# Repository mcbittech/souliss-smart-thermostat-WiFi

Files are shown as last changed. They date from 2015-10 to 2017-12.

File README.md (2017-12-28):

# souliss-smart-thermostat-WiFi


Wi-Fi Smart Thermostat based on Souliss IoT Framework

Youtube video:
https://youtu.be/Pk9kK5DvYXE

[Wiki-How to Compile & Upload](https://github.com/mcbittech/souliss-smart-thermostat-WiFi/wiki/SST---WiFi-Souliss-Smart-Thermostat-Wiki)

# Example of SST with 3D printed support & cover:
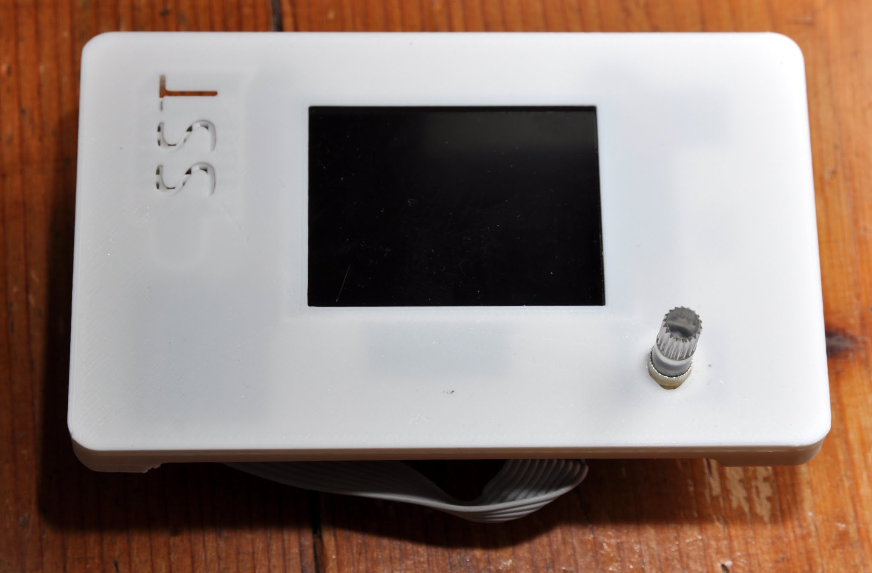
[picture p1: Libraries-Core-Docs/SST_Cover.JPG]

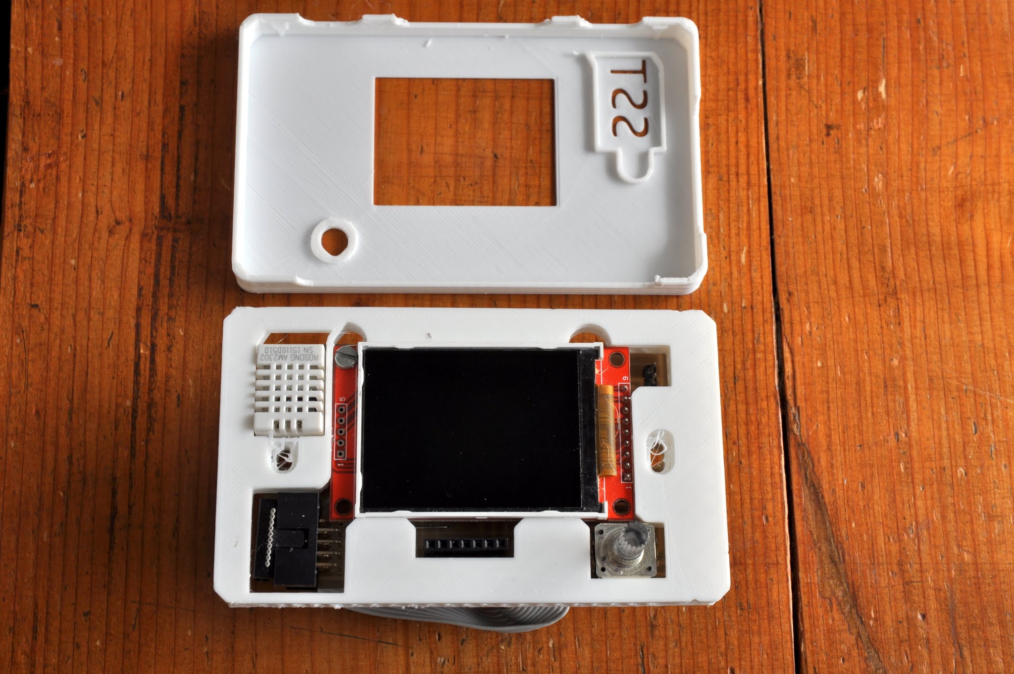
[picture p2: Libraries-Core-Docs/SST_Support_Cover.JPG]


# Example of layout 2:
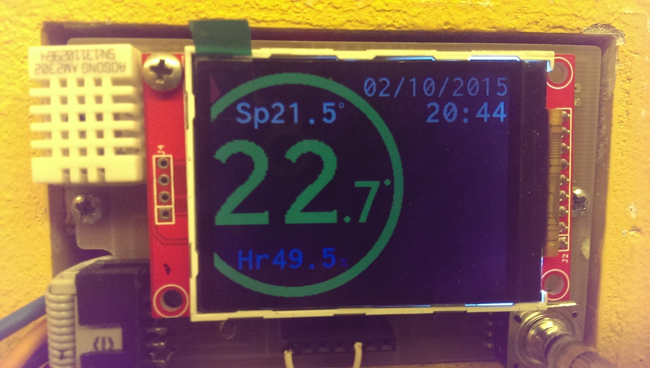
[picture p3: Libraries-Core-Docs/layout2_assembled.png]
layout2


# Example of layout 1:
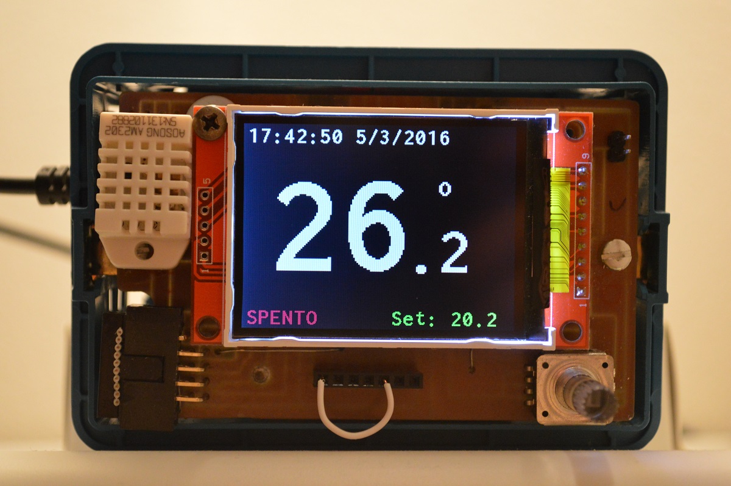
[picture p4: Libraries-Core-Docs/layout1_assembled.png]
layout2 layout1


# Example of chrono:
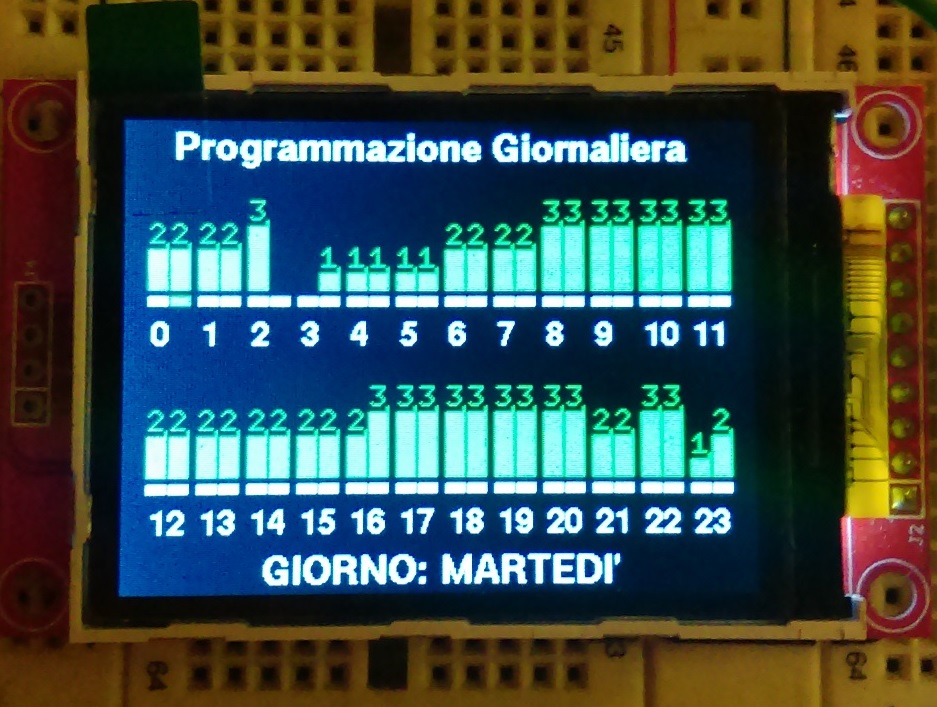
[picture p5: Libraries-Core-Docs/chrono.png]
chrono


# Bill of Material:
-Olimex ESP8266-EVB  
-ILI9341 with SPI connection, via UEXT connector  
-Rotary Encoder with pushbutton & status LED  
-DHT22 Temperature & Humidity Sensor  

# How to connect your system:
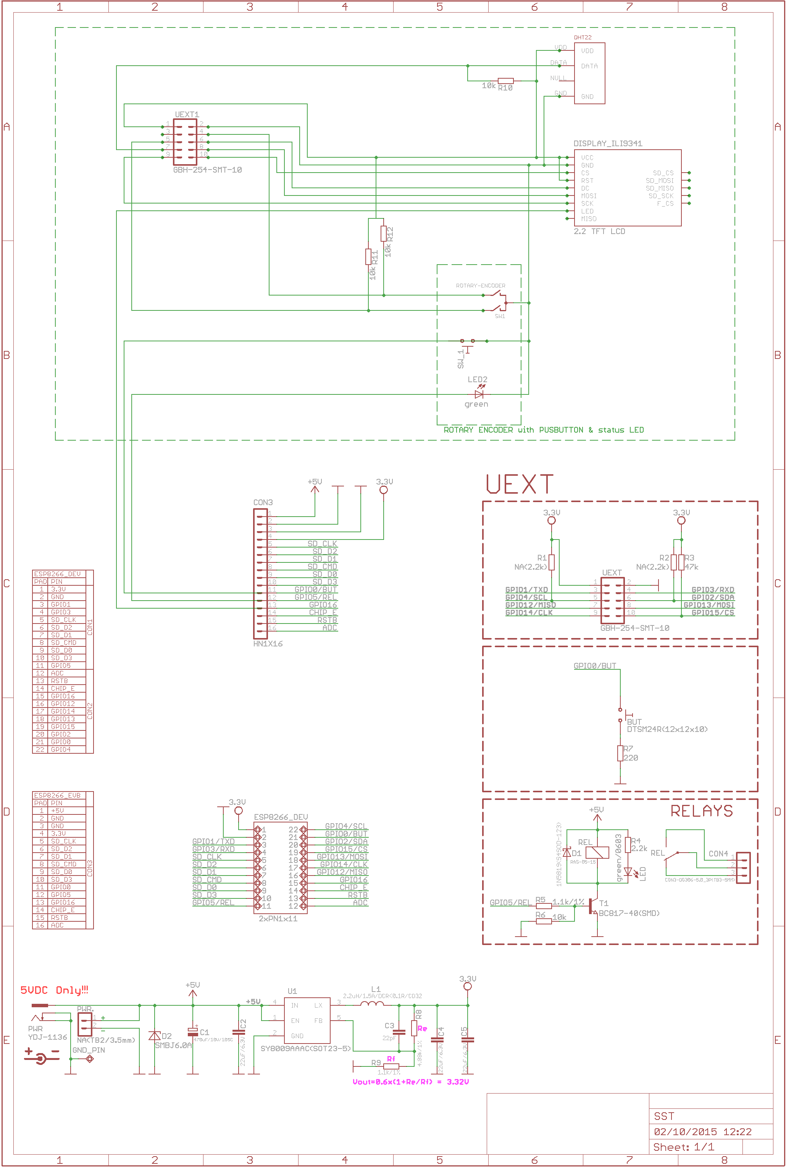
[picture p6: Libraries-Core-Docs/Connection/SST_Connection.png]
scheme


# Power up your system:
All the system require maximum about 200mA @5vdc, with relay ON and maximum brightness of the screen.
Minimum power required about 65mA, with relay OFF and minimum brightness.

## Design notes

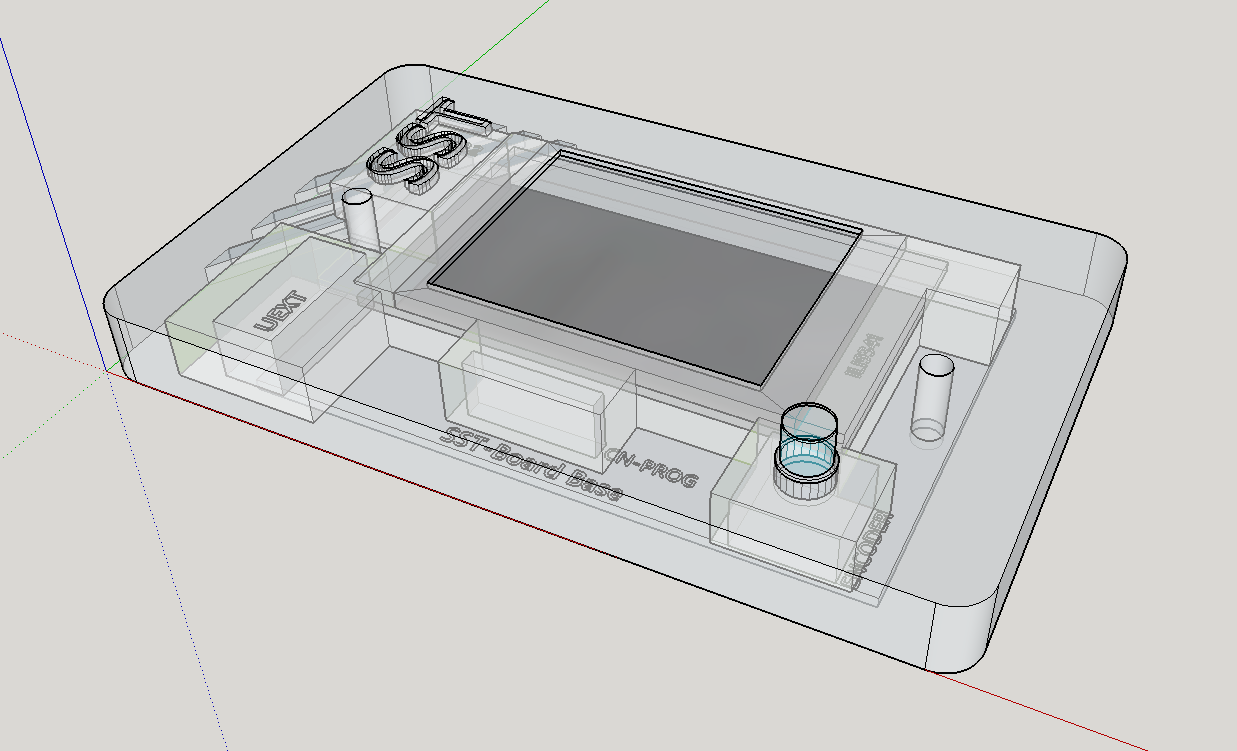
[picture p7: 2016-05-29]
Libraries-Core-Docs/MOSTRINA_3D/Prototipo.png

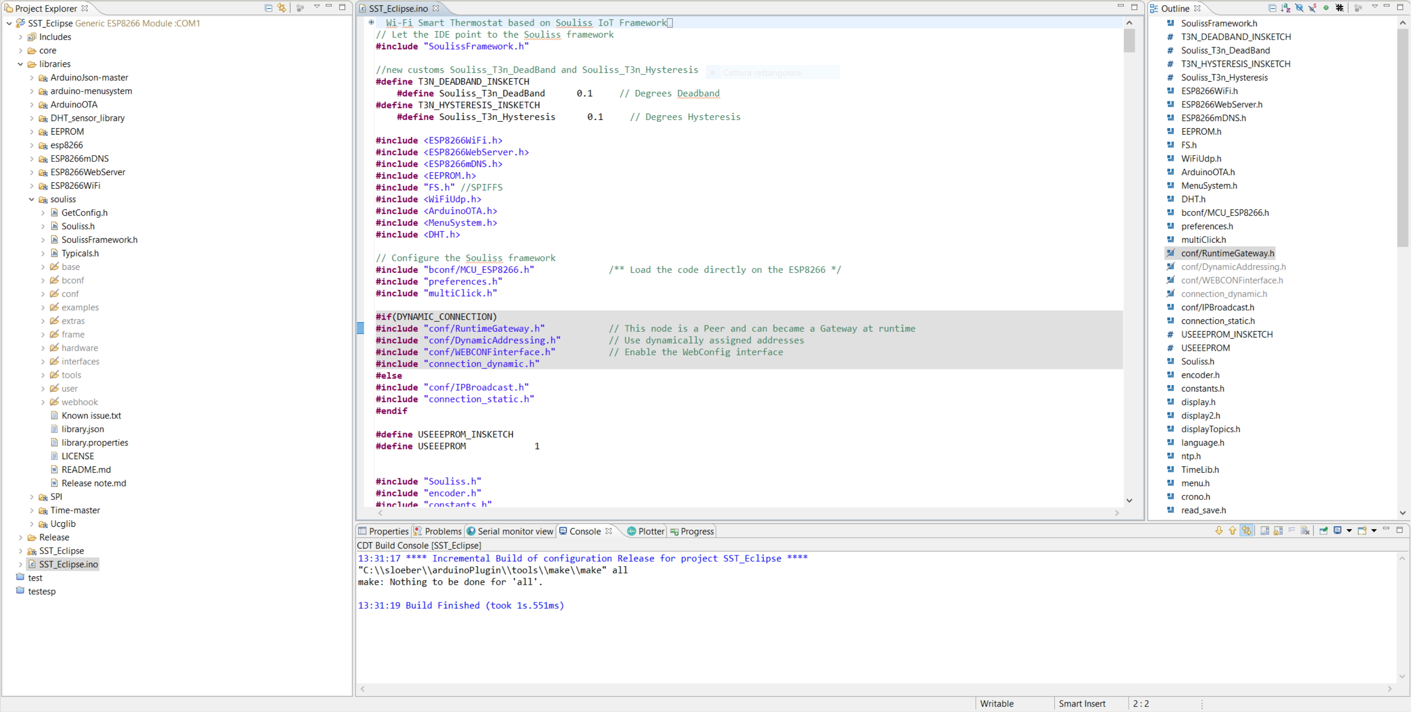
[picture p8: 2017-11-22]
Libraries-Core-Docs/SST_Eclipse.PNG

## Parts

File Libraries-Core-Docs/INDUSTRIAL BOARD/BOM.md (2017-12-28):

## BOM:
| Ref | Qty  | Value |
|:---|:---:|:---|
|C1 |1 |100n|
|C6,C5 |2 |470n 10v|
|D1 |1 |LED Rosso|
|D2 |1 |1N5819|
|D4 |1 |LED Verde|
|DHT1 |1 |DHT22|
|DISPLAY1 |1 |ILI9341|
|K2 |1 |CONN_3|
|P1,P2,P4 |3 |CONN_2|
|P3,P6 |2 |CONN_6|
|P5 |1 |CONN_5|
|POT1 |1 |EC12PL|
|Q1 |1 |BC818-40|
|R10,R5,*R9,R3,R14,R13,R16,R6  |8 |10k |
|R4,R1 |2 |1k |
|R7,R8,R2,R15  |4 |2.2k |
|RL1 |1 |RELAY_1RT |
|SW1 |1 |SW_PUSH |
|T1 |1 |VTX-214-005-105 |
|U1 |1 |ESP-12E |
|U2 |1 |LD1085-33 |

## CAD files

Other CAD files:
Libraries-Core-Docs/MOSTRINA_3D/Taglio.dwg
Libraries-Core-Docs/MOSTRINA_3D/Studio.skp

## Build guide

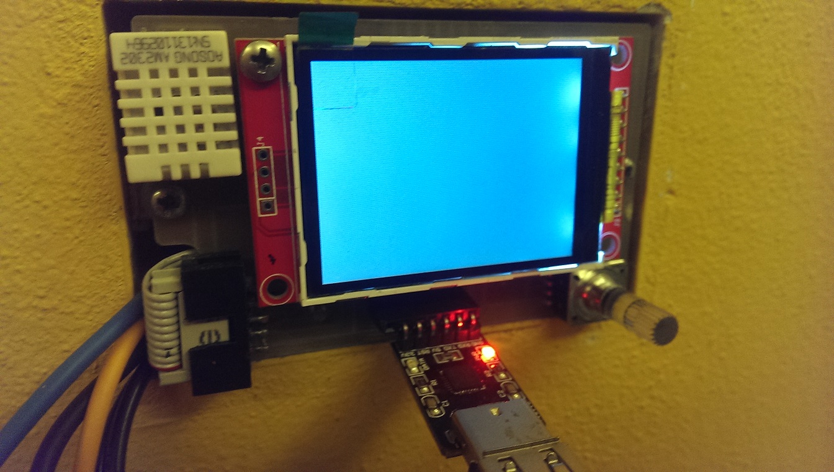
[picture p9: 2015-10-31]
Libraries-Core-Docs/howto_program.png

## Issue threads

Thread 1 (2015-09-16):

AnalogWrite function break display library

mcbittech, 2015-09-16:
Using AnalogWrite function on GPIO16(display LED backlight) will cause a break of display.

mcbittech, 2015-09-27:
With new library, i can't reproduce the problem.
Now working fine.

Closed 2015-09-27.

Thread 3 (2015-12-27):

Link non valido allo schema

dariocdj, 2015-12-27:
Ciao,
https://github.com/mcbittech/souliss-smart-thermostat-WiFi/blob/master/SST_Connection.png?raw=true
non si vede più....
Mi sta arrivando il materiale....
grazie

Dario

mcbittech, 2015-12-27:
Closed #3 with commit 544596e

mcbittech, 2015-12-27:
Closed #3
<https://github.com/mcbittech/souliss-smart-thermostat-WiFi/issues/3> with
commit 544596e
<https://github.com/mcbittech/souliss-smart-thermostat-WiFi/commit/544596eebb0ce489a9f942bdad8f74ab6ae5b138>

2015-12-27 21:49 GMT+01:00 Dario <notifications@github.com>:

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

--
P ********* Consideriamo l'ambiente prima di stampare questa e-mail ***
Think about environment before printing *********
Il contenuto di questo messaggio e-mail è privato e riservato al solo
destinatario. L'utilizzo non autorizzato può costituire reato. Se ricevuto
erroneamente siete pregati di cancellarlo e comunicarci via e-mail l'errata
ricezione.

dariocdj, 2015-12-27:
grazie

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

--

-------------------------------------------------------------------
                    Dario ??Cdj??

      On Email: cdj@deskservice.com
      On Web  : http://www.cdj.deskservice.com
      On Irc  : Undernet.org #altraitalia
      On ICQ  : Uin # 3986985
      On MSN  : dariocdj@hotmail.it
      On Skype: dariocdj

                Send me a fast reply !!!
------------------------------------------------------------------

Closed 2015-12-27.

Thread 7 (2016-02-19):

Arduino OTA

fazioa, 2016-02-19:

fazioa, 2016-02-24:
Implementata la modalità webupdater.
La relativa pagina web funziona e l'upload del nuovo sketch inizia correttamente.
L'upload non arriva al 50% e la pagina va in timeout.
Attendiamo upgrade del core e dell'IDE.

Closed 2016-02-24.

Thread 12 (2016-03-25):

OH continuous refresh on "off" state

dariocdj, 2016-03-25:
Today i 've found my sst in "off" position correctly but in oh logs:

14:35:35.935 [DEBUG] [.b.s.i.n.udp.UDPSoulissDecoder:80   ] - updateTIMESTAMP:  TIMESTAMP_Nodo12 ( 153) = 2016-03-21T14:35:35.935CET
14:35:35.938 [DEBUG] [.s.i.n.t.SoulissGenericTypical:100  ] - Update State. Name: power, Typ: 0x11, Node: 12, Slot: 0. New State: 0.0
14:35:35.951 [DEBUG] [.s.i.n.t.SoulissGenericTypical:100  ] - Update State. Name: heating, Typ: 0x13, Node: 12, Slot: 0. New State: 0.0
14:35:35.955 [DEBUG] [.s.i.n.t.SoulissGenericTypical:100  ] - Update State. Name: cooling, Typ: 0x13, Node: 12, Slot: 0. New State: 0.0
14:35:35.957 [DEBUG] [.s.i.n.t.SoulissGenericTypical:100  ] - Update State. Name: fan_low, Typ: 0x11, Node: 12, Slot: 0. New State: 0.0
14:35:35.961 [DEBUG] [.s.i.n.t.SoulissGenericTypical:100  ] - Update State. Name: fan_med, Typ: 0x11, Node: 12, Slot: 0. New State: 0.0
14:35:35.970 [DEBUG] [.s.i.n.t.SoulissGenericTypical:100  ] - Update State. Name: null, Typ: 0x11, Node: 12, Slot: 0. New State: 0.0
14:35:35.974 [DEBUG] [.s.i.n.t.SoulissGenericTypical:100  ] - Update State. Name: fan_auto_mode, Typ: 0x11, Node: 12, Slot: 0. New State: 0.0
14:35:35.977 [DEBUG] [.s.i.n.t.SoulissGenericTypical:100  ] - Update State. Name: heating_cooling, Typ: 0x11, Node: 12, Slot: 0. New State: 1.0
14:35:35.980 [DEBUG] [.b.s.i.n.udp.UDPSoulissDecoder:300  ] - decodeStateRequest: power (49). Thermostat= 128, Temp.Measured= 20.796875, Temp.SetPoint= 20.796875
14:35:35.991 [DEBUG] [.o.b.s.i.n.udp.UDPServerThread:61   ] - Packet received

This happen continuously...

fazioa, 2016-06-02:
Dario, the issue still exists?

dariocdj, 2016-06-02:
No close it, tnx

Closed 2016-06-02.

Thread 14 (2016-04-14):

Various bugs using ide 1.6.8, core 2.1 and Souliss_Branch_Core2

dariocdj, 2016-04-14:
Tried to modify main page with new OTA (working but erasing eeprom) but new core and souliss_branch_core2 introduce several bugs :
1) during crono programming moving encoder in setpoint area cause reset.
2) t31 work reversed. It start in heat mode but with no functional relay
3) sometimes system send lots of data to gateway (floods) with t31 reversed.
4) eeprom doesn't work well

Closed 2016-06-02.

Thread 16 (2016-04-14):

Moving Encoder in Topics page cause setpoint printing

dariocdj, 2016-04-14:
In layout2 When you move encoder while you are in topics page new setpoint is printed. And this is not good.

fazioa, 2016-06-02:
Only Circular layout is affected

dariocdj, 2016-06-02:
I know but no idea how to fix it....

mcbittech, 2017-12-11:
#54 solve this

Closed 2017-12-11.

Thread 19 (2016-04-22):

child lock

fazioa, 2016-04-22:
Proposta: doppio click per inserire il blocco bambini, nuovamente doppio click per disinserito.
Il blocco bambini dovrebbe impedire di cambiare il Setpoint

dariocdj, 2016-04-22:
+1

fazioa, 2016-08-15:
Done

https://github.com/mcbittech/souliss-smart-thermostat-WiFi/commit/65a79166d2863b79006466aa379e8db51ddd56f0

Closed 2016-08-15.

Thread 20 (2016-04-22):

Menu responsive

fazioa, 2016-04-22:
Rendere più reattiva la navigazione del menu

fazioa, 2016-06-02:
E' il refresh a video che rallenta la selezione. Occorre migliorere la funzione del file menu.cpp
void printMenu(Ucglib_ILI9341_18x240x320_HWSPI ucg)

Closed 2016-06-09.

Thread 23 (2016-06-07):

Ora legale

dariocdj, 2016-06-07:
Prevedere flag ora legale. Con timezone 1 segna un ora prima....

dariocdj, 2016-06-13:
Added DayLightSavingTime (ora legale) in getNtpTime function and in submenu "clock" but not considered when print time. Pheraps setSyncProvider(getNtpTime); doesn't work ?

fazioa, 2016-08-18:
Fixed
https://github.com/mcbittech/souliss-smart-thermostat-WiFi/commit/36d52be59ecdbdf8b41ebeaef9e481f595d6ddfe

Closed 2016-08-18.

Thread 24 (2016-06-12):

Layout Circular - Shift Digit

fazioa, 2016-06-12:
Some digit shift on the right when Hr is Nan

dariocdj, 2016-06-13:
In logs it shift after :
Refresh Temperature to: 2147483647.2147483647
Refresh Humidity to: nan
exactely...

fazioa, 2016-08-15:
With DTH22 NaN fix , it could be fixed

Closed 2016-08-15.

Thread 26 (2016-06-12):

Layout Circular freeze when print circles

fazioa, 2016-06-12:

mcbittech, 2016-06-12:
@fazioa can you explain better this issue?
Core ide etc...
With the released code i've never see this issue.

Il domenica 12 giugno 2016, fazioa <notifications@github.com> ha scritto:

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

--
P ********* Consideriamo l'ambiente prima di stampare questa e-mail ***
Think about environment before printing *********
Il contenuto di questo messaggio e-mail è privato e riservato al solo
destinatario. L'utilizzo non autorizzato può costituire reato. Se ricevuto
erroneamente siete pregati di cancellarlo e comunicarci via e-mail l'errata
ricezione.

mcbittech, 2016-09-21:
closed

Closed 2016-09-21.

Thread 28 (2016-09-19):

Child Lock not visible on layout 2

dariocdj, 2016-09-19:
Some printing of "child lock" is necessary on layout 2

dariocdj, 2016-09-23:
fixed but need refresh after changing state (locked or unclocked).
setUIChanged() unsuccessful !

dariocdj, 2016-09-26:
Need refresh

dariocdj, 2016-09-26:
Ok fixed reinitializing HomeScreen

Closed 2016-09-26.

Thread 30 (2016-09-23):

Layout2 Crono status in topics and menu pages

dariocdj, 2016-09-23:
When crono refresh, display status also if in topics or menu pages...

dariocdj, 2016-09-26:
Fixed with checkCronoStatus and printing status from main file only if crono is on, homepage is selected, layout is 2

Closed 2016-09-26.

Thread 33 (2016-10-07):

temperature decimal not diplay .4 or .9

mcbittech, 2016-10-07:
in temperature visualization you never see xx.4 or xx.9
bug of function dopovirgola()

mcbittech, 2016-10-07:
waiting for test

mcbittech, 2016-10-26:
Seems to be ok

Closed 2016-10-26.

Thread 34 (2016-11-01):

Files compiled with errors

igbor, 2016-11-01:
Files compiled with errors. Established Arduino AVR v1.6.11 ESP 8266 v2.3.0 Souliss v.7.2.1

C:\Users\igbor\Documents\Arduino\e05_ESP8266_SST_webconf\e05_ESP8266_SST_webconf.ino: In function 'void subscribeTopics()':

e05_ESP8266_SST_webconf:114: error: 'subscribedata' was not declared in this scope
   if (subscribedata(TOPIC1, mypayload, &mypayload_len)) {
                                                                                          ^
C:\Users\igbor\Documents\Arduino\e05_ESP8266_SST_webconf\e05_ESP8266_SST_webconf.ino: In function 'void publishHeating_ON_OFF()':

e05_ESP8266_SST_webconf:248: error: 'publishdata' was not declared in this scope
     publishdata(SST_HEAT_ONOFF, &HEAT_ON, 1);
                                                                            ^
e05_ESP8266_SST_webconf:250: error: 'publishdata' was not declared in this scope
     publishdata(SST_HEAT_ONOFF, &HEAT_OFF, 1);
                                                                              ^
exit status 1
'subscribedata' was not declared in this scope

fazioa, 2016-11-01:
In last Souliss release subscribedata as changed in sbscrb and publish
in pblsh

Look at .\souliss\base\PublishSubscribe.h

Tonino Fazio

2016-11-01 7:22 GMT+01:00 igbor <notifications@github.com>:

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

mcbittech, 2016-11-08:
@igbor have you solved?

igbor, 2016-11-09:
Thank you for all compiles fine, the author has made changes. Upgrade to github

Closed 2016-11-09.

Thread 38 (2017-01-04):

ESP-12E Random Soft WDT Resets

brunodymios, 2017-01-04:
Hi there,
I'm really interested in this project and I'm testing it on a NodeMCU ESP-12E development board.
I randomly receive software WDT resets. It can happen right after 10 minutes or a couple of hours, it is not sistematic. It happens both when powered with USB and with an external power supply (7805 connected to the Vin pin of the board).

Here you are the stacktrace I'm receiveing in the serial monitor window:

```
Refresh Circle White
Refresh Circle White OK
Refresh Circle Black
Refresh Circle Black OK
Refresh HOME Screen

Soft WDT reset

ctx: cont
sp: 3fff1640 end: 3fff1bd0 offset: 01b0

>>>stack>>>
3fff17f0:  3fff0a40 3fff1810 00000029 40215609
3fff1800:  00000000 3fff1ad8 3fff1ab8 4021a54b
3fff1810:  00000000 0000000e 00000005 00000030
3fff1820:  00000001 3fff1ad8 3fff1ab8 4021a864
3fff1830:  40215482 63045964 00000020 401076bc
3fff1840:  3fffc278 3fff1ad8 3fff1ab8 4021a8f3
3fff1850:  402154b1 00000030 3fff1ab8 4021ba14
3fff1860:  4021549b 3fff1ad8 3fff1ab8 4021bced
3fff1870:  00000025 0000005a 0000fff8 fffffff8
3fff1880:  000000b4 000000b4 0000004a 00000015
3fff1890:  4021549b 00000030 00000008 0000003b
3fff18a0:  00000025 00000039 3fff1ab8 40247f5d
3fff18b0:  fc0000ff 402154e0 402154e0 4021b27b
3fff18c0:  000000a4 00000055 27f40000 4021ad68
3fff18d0:  00000000 0000003b 00000000 fffffffc
3fff18e0:  0000003b 00000000 00000025 401076bc
3fff18f0:  4021a8a4 0000000f 3fffc230 0000003f
3fff1900:  00000000 3fff1ab8 3fff1b34 4021ae4d
3fff1910:  00000025 0000003e ffffffcf 00000000
3fff1920:  4021b97c 00000000 000000ff 3fff1ab8
3fff1930:  fffffffc 00000000 3fff1ab8 4021af03
3fff1940:  3fff1ab8 00000050 00000000 4021b000
3fff1950:  00000031 00000001 3fff1ab8 40219d28
3fff1960:  00009b98 00000000 3fff1ab8 3fff19f0
3fff1970:  3fff1ab0 00000000 3fff1ab0 40215685
3fff1980:  000000c5 00000002 3fff19ee 4021892c
3fff1990:  4000df64 00000030 00000011 3fff1ab0
3fff19a0:  00000031 0000000a 3fff1ab0 402160f1
3fff19b0:  3fff19ee 3fff1a30 3fff1ab8 4021a8f3
3fff19c0:  000000a3 3fff1a20 3fff19ed 402162ad
3fff19d0:  3fff00f0 3fff1a30 3fff1ab8 4021bd51
3fff19e0:  00000000 3fff1a20 3fff1ab8 3831b9b1
3fff19f0:  3fff1c00 3fff1aba 3fff1ab8 00000009
3fff1a00:  00000009 3fff1ab8 3fff1ab8 00000009
3fff1a10:  3fff1c18 3fff1ab8 3fff1ab8 00000009
3fff1a20:  3fff1c18 00000012 3fff1ab0 4021630b
3fff1a30:  00000000 014000f0 3fff1ab8 40247f29
3fff1a40:  3fff1c18 3fff1ab8 3fff1ab0 40216324
3fff1a50:  41973333 41973333 3fff1ab0 4020a751
3fff1a60:  00000012 41a00000 4288cccd 402161ec
3fff1a70:  00000000 3fff1c18 3fff1c18 40216238
3fff1a80:  3fff0226 3fff1c18 3fff1ab8 3fff0ba4
3fff1a90:  00000000 3fff0224 3fff00f0 4020ebc3
3fff1aa0:  40000f83 00000030 00000020 401076bc
3fff1ab0:  3ffe89b0 00000000 00a00001 00000078
3fff1ac0:  4021bba8 4021a880 4021a8a4 014000f0
3fff1ad0:  4021b97c 402154e0 0000003b 00000000
3fff1ae0:  00010042 00010008 00000000 ff660000
3fff1af0:  00000000 00000000 00000000 00000000
3fff1b00:  00000000 00000000 00000000 00000000
3fff1b10:  00000000 00000000 00000000 00000000
3fff1b20:  00000000 00000000 014000f0 4024e9e4
3fff1b30:  4021a9dc 4024ef11 001ffffc 3e253a1f
3fff1b40:  00000001 0506025f 05010606 003e2507
3fff1b50:  30f42ef3 098400f3 000014de 00000000
3fff1b60:  02fff42e ffffff0f ffffffff 07ffffff
3fff1b70:  0000010d 4021a8a4 4021a880 0050fffc
3fff1b80:  feefef00 3fff2b34 3fff267c 00000000
3fff1b90:  00000000 00000000 feefeffe feefeffe
3fff1ba0:  00000000 00000000 00000001 3fff0ba4
3fff1bb0:  3fffdad0 00000000 3fff0b9c 4021588c
3fff1bc0:  feefeffe feefeffe 3fff0bb0 40100718
<<<stack<<<

 ets Jan  8 2013,rst cause:2, boot mode:(3,6)

load 0x4010f000, len 1384, room 16
tail 8
chksum 0x2d
csum 0x2d
v3de0c112
~ld
ÿ

```
Addresses shown before the stack trace are not fixed, they change between subsequent crashes. Here's another crash log, right after the first one:

```
Refresh Circle Green
Refresh Circle Green OK

Soft WDT reset

ctx: cont
sp: 3fff16c0 end: 3fff1bd0 offset: 01b0

>>>stack>>>
```

At the beginning of the code, in the setup() I've added some additional debug info:
```
Heap: 37424
Boot Vers: 31
CPU: 80
SDK: 1.5.3(aec24ac9)
Chip ID: 422598
Flash ID: 1458400
Flash Size: 4194304
Vcc: 65535
```

Boot mode (3,6) seems to be correct: booting from SPI flash memory, while the reset cause (2) means that there is something with the RST pin. I checked the connections and they are OK and I added a 10k pull-up resistor on the GPIO 0 pin, with no luck.

Anyone facing this problem? Any hint to solve it?

Thank You

mcbittech, 2017-01-04:
Hello @brunodymios ,
what kind of release are you working on? your general hardware and schematics?
Are you uploading your code following wiki?
https://github.com/mcbittech/souliss-smart-thermostat-WiFi/wiki/SST---WiFi-Souliss-Smart-Thermostat-Wiki

Flavio

brunodymios, 2017-01-04:
Hi @mcbittech, thanks for your answer.
Yes, I followed the wiki you linked me to setup the firmware (branch "friariello" for souliss and this repo for the thermostat-specific code). I'm using Arduino IDE **1.6.5** with ESP8266 board version **2.3.0** installed.

I'm using a **NodeMCU** board found on banggood. [Here's the link](http://www.banggood.com/it/NodeMcu-Lua-WIFI-Internet-Things-Development-Board-Based-ESP8266-CP2102-Wireless-Module-p-1097112.html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).
The LCD is similar to your one [Link](http://www.banggood.com/it/2_2-Inch-Serial-TFT-SPI-LCD-Screen-Module-HD-240-x-320-5110-Compatible-p-912854.html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).
DHT22 is used for Temp/Humidity sensor.

I didn't connect any relay for the moment in order to minimize the complexity of the schematic for testing. I'm using a simple resistor + led to simulate it. All the schematic is built on a breadboard to prototype.

The device is generally working well: temperature and humidity correctly displayed, user menu, set point, etc. Reboots seems to be really random, always with same reason (2 - rst pin and boot mode 3,6) but stack traces point to different memory locations.

Bruno

mcbittech, 2017-01-04:
@brunodymios
Can you try with last IDE supported 1.6.12 please, with [this ](https://github.com/mcbittech/souliss-smart-thermostat-WiFi/releases/tag/SST_v1.2_prewbs_STABLE)version of SST?
Your rst pin are floating or connected?
We haven't tried with this ESP board, if this tests doesen't work, we must go deeper inside hardware/pinout of your board. In this case please attach a schematics of your board.

Flavio

brunodymios, 2017-01-04:
@mcbittech
I've tried right now. I updated the IDE to the 1.6.12 version and I used the version of SST you indicated me (including libraries). I added a 10k pull-up resistor to the RST and GPIO0 pins.

I received a reboot after a couple of minutes the following stack trace:
```
>>>stack>>>
3fff18c0:  00000000 00000000 3fff1b98 40219b64
3fff18d0:  3fff0a30 3fff18f0 00000008 402145f3
3fff18e0:  00000000 3fff1bb8 3fff1b98 4021a387
3fff18f0:  3f00ff66 40101933 04000000 00000001
3fff1900:  00000001 3fff1bb8 3fff1b98 4021a6a0
3fff1910:  00000000 00000000 3fffc230 4000050c
3fff1920:  4021ace4 3fff1bb8 3fff1b98 4021a72f
3fff1930:  4021ad35 4024e9fc 3fff1b98 4021b850
3fff1940:  00000000 3fff1bb8 3fff1b98 4021bb29
3fff1950:  00000007 00000034 0000002a 0000002a
3fff1960:  00000068 00000068 0000000e 00000015
3fff1970:  00000000 3fff1b98 00000020 00000015
3fff1980:  0000000c 00000007 3fff1b98 40247d45
3fff1990:  4021a665 00000030 3fffc230 4021b0b7
3fff19a0:  40219ed8 00000030 0000001d 4021aba4
3fff19b0:  00000019 00000015 00000001 00000015
3fff19c0:  00000015 00000000 00000007 00000066
3fff19d0:  00000000 00000085 00000000 0000001e
3fff19e0:  00000007 3fff1b98 3fff1c14 4021ac92
3fff19f0:  00000025 0000003e ffffffcf 00000000
3fff1a00:  00000000 00000007 00000055 3fff1b98
3fff1a10:  fffffffc 00000000 3fff1b98 4021ad3f
3fff1a20:  0000006e 00000050 00000000 4021ae3c
3fff1a30:  00000032 00000001 3fff1b98 40219b64
3fff1a40:  00009b10 00000000 3fff1b98 3fff1ad0
3fff1a50:  3fff1b90 00000000 3fff1b90 40214679
3fff1a60:  000000c5 00000002 3fff1ace 402187a4
3fff1a70:  3fff0a30 00000001 3fff1b98 3fff1b90
3fff1a80:  00000032 0000000a 3fff1b90 40215d1d
3fff1a90:  3fff1ace 3fff1b10 3fff1b98 4021a72f
3fff1aa0:  00000000 3fff1b00 3fff1acd 40215ed9
3fff1ab0:  00000009 3fff1b10 3fff1b98 4021bb8d
3fff1ac0:  00000000 3fff1b00 3fff1b98 3132b7ed
3fff1ad0:  3fff0b00 3fff1b9a 3fff1b98 00000004
3fff1ae0:  00000009 3fff1b98 3fff1b98 00000004
3fff1af0:  3fff0bc0 3fff1b98 3fff1b98 00000004
3fff1b00:  3fff0bc0 00000015 3fff1b90 40215f37
3fff1b10:  00000000 014000f0 3fff1b98 40247d11
3fff1b20:  3fff0bc0 3fff1b98 3fff1b90 40215f50
3fff1b30:  41ab3333 41ab3333 3fff1b90 4020a751
3fff1b40:  00000015 41a00000 4271999a 40215e18
3fff1b50:  00000000 3fff0bc0 3fff0bc0 40215e64
3fff1b60:  40217cd8 3fff0bc0 3fff1b98 3fff0c7c
3fff1b70:  00000000 3fff0224 3fff00f0 4020eae7
3fff1b80:  40000f83 00000030 0000000e ffffffff
3fff1b90:  3ffe89b0 00000000 00a00001 00000078
3fff1ba0:  4021b9e4 4021a6bc 4021a6e0 014000f0
3fff1bb0:  4021b7b8 402144d4 002a0087 0000ff66
3fff1bc0:  0001000e 00010000 00000000 ff660000
3fff1bd0:  00000000 00000000 00000000 00000000
3fff1be0:  00000000 00000000 00000000 00000000
3fff1bf0:  00000000 00000000 00000000 00000000
3fff1c00:  00000000 00000000 014000f0 4024e7cc
3fff1c10:  4021a818 4024ed21 001ffffc 3e251519
3fff1c20:  00000004 0506025f 05010606 003e2507
3fff1c30:  30f42ef3 098400f3 000014de 00000000
3fff1c40:  02fff42e ffffff0f ffffffff 07ffffff
3fff1c50:  0000010d 4021a6e0 4021a6bc 0050fffc
3fff1c60:  feefef00 3fff2b3c 3fff2684 00000000
3fff1c70:  00000000 00000000 feefeffe feefeffe
3fff1c80:  00000000 00000000 00000001 3fff0c7c
3fff1c90:  3fffdad0 00000000 3fff0c74 40216e30
3fff1ca0:  feefeffe feefeffe 3fff0c90 40100718
<<<stack<<<
```

Decoding it using the [ESP Exception Decoder](https://github.com/me-no-dev/EspExceptionDecoder) I got this information:
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
mcbittech, 2017-01-04:
@brunodymios
try to add some yield(); from [line](https://github.com/mcbittech/souliss-smart-thermostat-WiFi/blob/master/e05_ESP8266_SST_webconf/e05_ESP8266_SST_webconf.ino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)

something like this:
**yield();**
            display_layout2_print_circle_white(ucg);
**yield();**
            display_layout2_print_circle_black(ucg);
**yield();**
            display_layout2_HomeScreen(ucg, temperature, humidity, setpoint);
**yield();**
            display_layout2_print_datetime(ucg);
**yield();**

Then try to move your display pin to other free pins, pin like 2 and 15 to other position.

Let me now

Flavio

brunodymios, 2017-01-05:
Hi @mcbittech
following your indication I added the yield instructions and the device was up and running from 4pm yesterday to 11am this morning without reboots.

As a final test, I flashed again the version without the yield instructions and I saw again a reboot in about 20 minutes.

What do you think? Can we consider this issue closed?

Thank You
Bruno

mcbittech, 2017-01-05:
@brunodymios i don't think this is an issue related to SST code, but i think this is an ESP core issue.
for the moment i commit new code changes on SST side.
Keep your SST on test and let me now please 👍
For the moment we keep open this issue for some days.

Flavio

brunodymios, 2017-01-06:
Completely agree with you, this is not an issue of the SST but rather an improvement of it to take into account this issue in the ESP core.
I'll leave the SST on for testing and I'll let you know.

Thanks.
Bruno

mcbittech, 2017-02-04:
@brunodymios have any news?

Thanks
Flavio

brunodymios, 2017-02-25:
Did not face the issue again 👍

mcbittech, 2017-11-22:
solved

Closed 2017-11-22.

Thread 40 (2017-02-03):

Encoder demoltiplica

fazioa, 2017-02-03:
Encoder troppo sensibile

mcbittech, 2017-02-04:
Non mi piace l'idea di demoltiplicare.
Può essere un'idea migliore renderlo proporzionale alla velocità di rotazione?
Ovvero, più sarà bassa la velocità più basso sarà il valore di incremento....

fazioa, 2017-02-04:
Sono d'accordo.

Il sab 4 feb 2017, 15:03 Flavio <notifications@github.com> ha scritto:

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

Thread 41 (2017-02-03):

Menù - asterisco

fazioa, 2017-02-03:
Sistemare comportamento menù

dpeddi, 2017-02-23:
sto provando ad aggiornare al master di arduino-menusystem, dovrebbe semplificare la gestione della selezione

fazioa, 2017-02-23:
Bene.
Attendiamo per i test.

Il gio 23 feb 2017, 17:41 dpeddi <notifications@github.com> ha scritto:

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

dpeddi, 2017-02-24:
fatto a vecchio... mi pare proprio meglio

fazioa, 2017-02-25:
Hai verificato che compili si esp?

dpeddi, 2017-02-25:
La patch?

Si, compila e testata...

Funziona come previsto

Il 25/feb/2017 02:40 PM, "fazioa" <notifications@github.com> ha scritto:

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

Closed 2017-11-22.

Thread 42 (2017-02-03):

Sospensione crono

fazioa, 2017-02-03:
Sospendere il crono per 30 minuti quando si imposta manualmente il setpoint

mcbittech, 2017-02-04:
Non sono del tutto d'accordo.
In ogni caso se vuoi testarlo è molto semplice, basta triggerare la chiamata del crono ogni tempo che vuoi.
Se non ricordo male basta portare:
      if (getCrono()) {
        Serial.println("CRONO: aggiornamento");
        setSetpoint(checkNTPcrono(ucg));
        setEncoderValue(checkNTPcrono(ucg));
        Serial.print("CRONO: setpoint: "); Serial.println(setpoint);
      }
che adesso è chiamata in una slow_50s, in una slow_xx che puoi configurare a piacimento.

dariocdj, 2017-12-11:
Io lo farei per 2/3 ore... Mezz'ora manco te ne accorgi... Pop-up di conferma necessario

Closed 2017-02-04.

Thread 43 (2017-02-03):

Il setpoint non ha limiti

dpeddi, 2017-02-03:
v 1.2

Andrebbe impostato un limite negativo e positivo al setpoint.

Ruotando all'infinito vengono generati setpoint infiniti che alterano la visualizzazione della grafica (layout circolare)

la cosa più semplice è impostare il setpoint massimo a 50° e minimo a 5° (-15 se proprio si vuole essere generosi)

mcbittech, 2017-02-04:
Si, questo è un bug noto, mai sistemato però.
Aggiorno il branch in sviluppo.

Grazie
Flavio

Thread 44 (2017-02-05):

V12 - Layout circolare - regolazione SP in topic non torna nel menù corretto

dpeddi, 2017-02-05:
Questo problema si verifica quando si utilizza il layout circolare e ci si trova  nella pagina dei topic e si va a ruotare l'encoder.

Mentre in layout lineare, si torna nella "pagina" principale, nel layout circolare, si rimane nella schermata  dei topic che viene  "sporcata" con la configurazione del sp.

dpeddi, 2017-03-06:
doppio (#16)

Closed 2017-03-06.

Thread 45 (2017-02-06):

backlight non abbastanza progressiva e con flickering

dpeddi, 2017-02-06:
vedi:
https://github.com/esp8266/Arduino/issues/836

Si potrebbe provare a verificare se il seguente git migliora la situazione
https://github.com/StefanBruens/ESP8266_new_pwm

mcbittech, 2017-11-22:
Il problema è relativo ai core, ma non solo, la progressività è relativa alla gestione delle fasi Souliss. Vediamo in futuro se possibile cambiare e diminuire tali fasi.

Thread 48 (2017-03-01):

wbserver_beta non compila con DYNAMIC = 1

dpeddi, 2017-03-01:
Sembra non sia possibile a compilare wbserver_beta con DYNAMIC =1

questo perché si formano dei conflitti con ESPAsynWebServer e
#include "conf/RuntimeGateway.h"            // This node is a Peer and can became a Gateway at runtime
#include "conf/DynamicAddressing.h"         // Use dynamically assigned addresses
#include "conf/WEBCONFinterface.h"          // Enable the WebConfig interface

occorre quindi capire se souliss passerà a ESPAsyncWebServer oppure se sarà necessario incorporare in SST una webconf  basata su ESPAsynWebServer, più o meno come ha fatto gmag11(https://github.com/gmag11/FSBrowserNG) e perché no salvare su spiffs anche la configurazione del wifi.

Trà l'altro (se ci si stà nella flash) potrebbe essere interessante includere l'editor ACE (potrebbe tornar comodo per modificare alcune configurazioni... avrei in mente di sfruttarlo per modificare l'abbinamento topic/espid senza doverlo cablare su preferences).. ma questo è un altro film...

Segue l'errore:
---
Compiling .pioenvs\e05_ESP8266_SST_webconf\lib\ESP8266WebServer\ESP8266WebServer.o
In file included from D:/Apps/Atom_x64/projects/souliss-smart-thermostat-WiFi_wbserver_beta/e05_ESP8266_SST_webconf/e05_ESP8266_SST_webconf.ino:65:0:
D:\Apps\Atom_x64\.platformio\packages\framework-arduinoespressif8266\libraries\ESP8266WebServer\src/ESP8266WebServer.h:30:19: error: redeclaration of 'HTTP_ANY'
enum HTTPMethod { HTTP_ANY, HTTP_GET, HTTP_POST, HTTP_PUT, HTTP_PATCH, HTTP_DELETE, HTTP_OPTIONS };

(souliss\interfaces\mcu_esp8266\webconfig\webconfig.cpp ESP8266WebServer server(HTTP_PORT); )

e

In file included from .piolibdeps\souliss/Souliss.h:168:0,
from D:/Apps/Atom_x64/projects/souliss-smart-thermostat-WiFi_wbserver_beta/e05_ESP8266_SST_webconf/e05_ESP8266_SST_webconf.ino:89:
.piolibdeps\souliss/tools/store/store.cpp: In function 'void Store_Init()':
.piolibdeps\souliss/tools/store/store.cpp:37:3: error: 'EEPROM' was not declared in this scope

EEPROM.begin(STORE__SIZE);
^

per lo stesso motivo

dpeddi, 2017-04-22:
prerequisito: creata pull request https://github.com/souliss/souliss/pull/292

dariocdj, 2017-12-09:
credo che hai già mergiato la mia modifiche dove extern web server lo fa indipendentemente se dinamic=1 o no.....

mcbittech, 2017-12-11:
ok, chiudo perchè era vecchio, in attesa di trasferimento

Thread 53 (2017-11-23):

PCB disponibile?

katodo, 2017-11-23:
non so se è corretto aprire una issue anche per questo ma... esiste già un PCB di questo progetto? Volevo fare qualche prova ma odio le millefori e mi stavo per cimentare nel disegno ma se c'è qualcosa di pronto molto meglio :)

mcbittech, 2017-11-23:
Ciao @katodo ,
no, non è corretto, comunque puoi trovare qui sul repo una versione da fresare qui:
https://github.com/mcbittech/souliss-smart-thermostat-WiFi/blob/master/Libraries-Core-Docs/Connection/PCB_layout.pdf
una versione da fotoincidere qui:
https://github.com/mcbittech/souliss-smart-thermostat-WiFi/blob/wbserver_beta/Libraries-Core-Docs/sst_pcb.fzz
una versione "industriale" qui:
 https://groups.google.com/d/msgid/souliss-it/bcdb9e0e-6643-496b-9813-10556e2531fb%40googlegroups.com

Closed 2017-11-23.

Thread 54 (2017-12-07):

Stampa aggiornamento setpoint se sono nelle pagine di topic

pacioc193, 2017-12-07:
Se viene cambiato il setpoint mentre si è nel pannello di pagine topic viene stampato a schermo il setpoint.

pacioc193, 2017-12-07:
SHIFT_50ms(0) {
      //set point attuale
      setpoint = Souliss_SinglePrecisionFloating(memory_map + MaCaco_OUT_s + SLOT_THERMOSTAT + 3);
      //Stampa il setpoint solo se il valore dell'encoder è diverso da quello impostato nel T31
      switch (SSTPage.actualPage) {
        case PAGE_MENU :
          if (!getMenuEnabled()) {
            SSTPage.actualPage = PAGE_HOME;
            initScreen();
            setUIChanged();
          }
          break;
        case PAGE_CRONO :
          break;
        case PAGE_HOME:
          if (arrotonda(getEncoderValue()) != arrotonda(encoderValue_prec) && !bChildLock) {
            FADE = 1;
            //TICK TIMER
            timerDisplay_setpoint_Tick();
            //SETPOINT PAGE ////////////////////////////////////////////////////////////////

            if (getLayout1()) {
              SERIAL_OUT.println("display_setpointPage - layout 1");
              display_layout1_background(ucg, arrotonda(getEncoderValue()) - arrotonda(setpoint));

              display_layout1_setpointPage(ucg, getEncoderValue(), temperature, humidity, getSoulissSystemState());
            }
            else if (getLayout2()) {
              SERIAL_OUT.println("display_setpointPage - layout 2");
              display_layout2_Setpoint(ucg, getEncoderValue(), getSoulissSystemState(), bChildLock);
            }
          }
          encoderValue_prec = getEncoderValue();
          break;
        default:
          break;
      }
    }

pacioc193, 2017-12-07:
` SHIFT_50ms(0) {
      //set point attuale
      setpoint = Souliss_SinglePrecisionFloating(memory_map + MaCaco_OUT_s + SLOT_THERMOSTAT + 3);
      //Stampa il setpoint solo se il valore dell'encoder è diverso da quello impostato nel T31
      switch (SSTPage.actualPage) {
        case PAGE_MENU :
          if (!getMenuEnabled()) {
            SSTPage.actualPage = PAGE_HOME;
            initScreen();
            setUIChanged();
          }
          break;
        case PAGE_CRONO :
          break;
        case PAGE_HOME:
          if (arrotonda(getEncoderValue()) != arrotonda(encoderValue_prec) && !bChildLock) {
            FADE = 1;
            //TICK TIMER
            timerDisplay_setpoint_Tick();
            //SETPOINT PAGE ////////////////////////////////////////////////////////////////

            if (getLayout1()) {
              SERIAL_OUT.println("display_setpointPage - layout 1");
              display_layout1_background(ucg, arrotonda(getEncoderValue()) - arrotonda(setpoint));

              display_layout1_setpointPage(ucg, getEncoderValue(), temperature, humidity, getSoulissSystemState());
            }
            else if (getLayout2()) {
              SERIAL_OUT.println("display_setpointPage - layout 2");
              display_layout2_Setpoint(ucg, getEncoderValue(), getSoulissSystemState(), bChildLock);
            }
          }
          encoderValue_prec = getEncoderValue();
          break;
        default:
          break;
      }
    }`

pacioc193, 2017-12-07:
case PAGE_HOME:
          if (arrotonda(getEncoderValue()) != arrotonda(encoderValue_prec) && !bChildLock) {
            FADE = 1;
            //TICK TIMER
            timerDisplay_setpoint_Tick();
            //SETPOINT PAGE ////////////////////////////////////////////////////////////////

            if (getLayout1()) {
              SERIAL_OUT.println("display_setpointPage - layout 1");
              display_layout1_background(ucg, arrotonda(getEncoderValue()) - arrotonda(setpoint));

              display_layout1_setpointPage(ucg, getEncoderValue(), temperature, humidity, getSoulissSystemState());
            }
            else if (getLayout2()) {
              SERIAL_OUT.println("display_setpointPage - layout 2");
              display_layout2_Setpoint(ucg, getEncoderValue(), getSoulissSystemState(), bChildLock);
            }
          }
          encoderValue_prec = getEncoderValue();
          break;
        default:
          break;

pacioc193, 2017-12-10:
Questo è stato risolto quando hai mergiato la mia pull request

mcbittech, 2017-12-11:
Si, solo su branch webserver, lascio aperto fino al merge su master

mcbittech, 2017-12-11:
@dariocdj sarebbe apprezzato un test incrociato da parte tua, attendiamo esiti

mcbittech, 2017-12-11:
@pacioc193 era già aperto questo issue, vedi #16.
cerchiamo di fare attenzione e non fare duplicati se possibile.

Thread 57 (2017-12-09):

Override Crono al cambio manuale del setpoint

mcbittech, 2017-12-09:
Sarebbe utile disabilitare il crono, per il giorno in corso(ma da valutare), ad un cambio manuale del Setpoint.
Sarebbe utilissimo anche avere la possibilità di scegliere se attivare l'override, tramite cambio pagina e scelta con click encoder.
Esempio:
- ruoto encoder con crono attivo
- senza cambiare setpoint, mi porto su una nuova pagina con la domanda "vuoi attivare un setpoint manuale con crono attivo?"
- avere la possibilità di selezionare si\no
In caso affermativo, si può spostare il setpoint a piacere e il crono viene disattivato per il giorno intero.
In caso di spostamento del setpoint sarebbe utile segnalarlo con una scritta "OVERRIDE MANUALE" a display.

mcbittech, 2017-12-11:
Uno spunto si può prendere sull'issue #42, con @fazioa avevamo già discusso di questo.

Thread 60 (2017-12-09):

Funzione PowerFull da sAPP e stampa su display

mcbittech, 2017-12-09:

pacioc193, 2017-12-12:
Purtroppo non conosco bene sAPP e il suo funzionamento, nel mentre ho aggiunto l'opzione a schermo POWERFULL, per problemi di spazio ho dovuto abbreviare il termine... Sarà possibile modificare la stringa dal "language.h"

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

marcio23, 2018-12-05:
Salve...qualcuno può aiutarmi?

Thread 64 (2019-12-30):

dove acquistare il rotary encoder ?

lucacalcaterra, 2019-12-30:
Sapete darmi un consiglio su dove acquistare l'encoder rotativo con pulsante e luce ?

ps. ho dei nodi souliss per tutta casa, l'unico problema sono i t31 che non funzionano bene con openhab. Sono indeciso se valga la pena o meno realizzare il termostato sst ...

mcbittech, 2019-12-30:
Ciao Luca,
SST usa anche un T31(che sarebbe da sistemare se non ricordo male).
Per l’encoder lo trovi un po’ dappertutto, esempio:
https://www.robotstore.it/Encoder-Rotativo-Illuminato-Rosso-Verde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

Flavio

Il giorno lun 30 dic 2019 alle 17:56 Luca Calcaterra <
notifications@github.com> ha scritto:

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
--
P ********* Consideriamo l'ambiente prima di stampare questa e-mail ***
Think about environment before printing *********
Il contenuto di questo messaggio e-mail è privato e riservato al solo
destinatario. L'utilizzo non autorizzato può costituire reato. Se ricevuto
erroneamente siete pregati di cancellarlo e comunicarci via e-mail l'errata
ricezione.

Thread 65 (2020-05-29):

Alimentazione

marcostrullato, 2020-05-29:
Hi everyone,

this is not really an issue, but i can't find any other way to communicate with who is part of the project. Maybe @mcbittech the project owner? I'm writing in English so that anyone can read and understand my message.

I see a component of the project is [ESP8266-EVB](https://www.olimex.com/Products/IoT/ESP8266/ESP8266-EVB/open-source-hardware). If I buy it, is it enough? I'm asking because I see there're the sketches with a board to print, and the project documentation has rooms for improvements. Probably I need to add the dht22 sensor, but what else?

Question:
What about powering the thermostat via 230V? I see there's another model ([this](https://www.olimex.com/Products/IoT/ESP8266/ESP8266-EVB-BAT/open-source-hardware)) that allows a battery source, but this is not what I want.
Maybe I can add a step down converter, or a transformer... ideas?

Regards

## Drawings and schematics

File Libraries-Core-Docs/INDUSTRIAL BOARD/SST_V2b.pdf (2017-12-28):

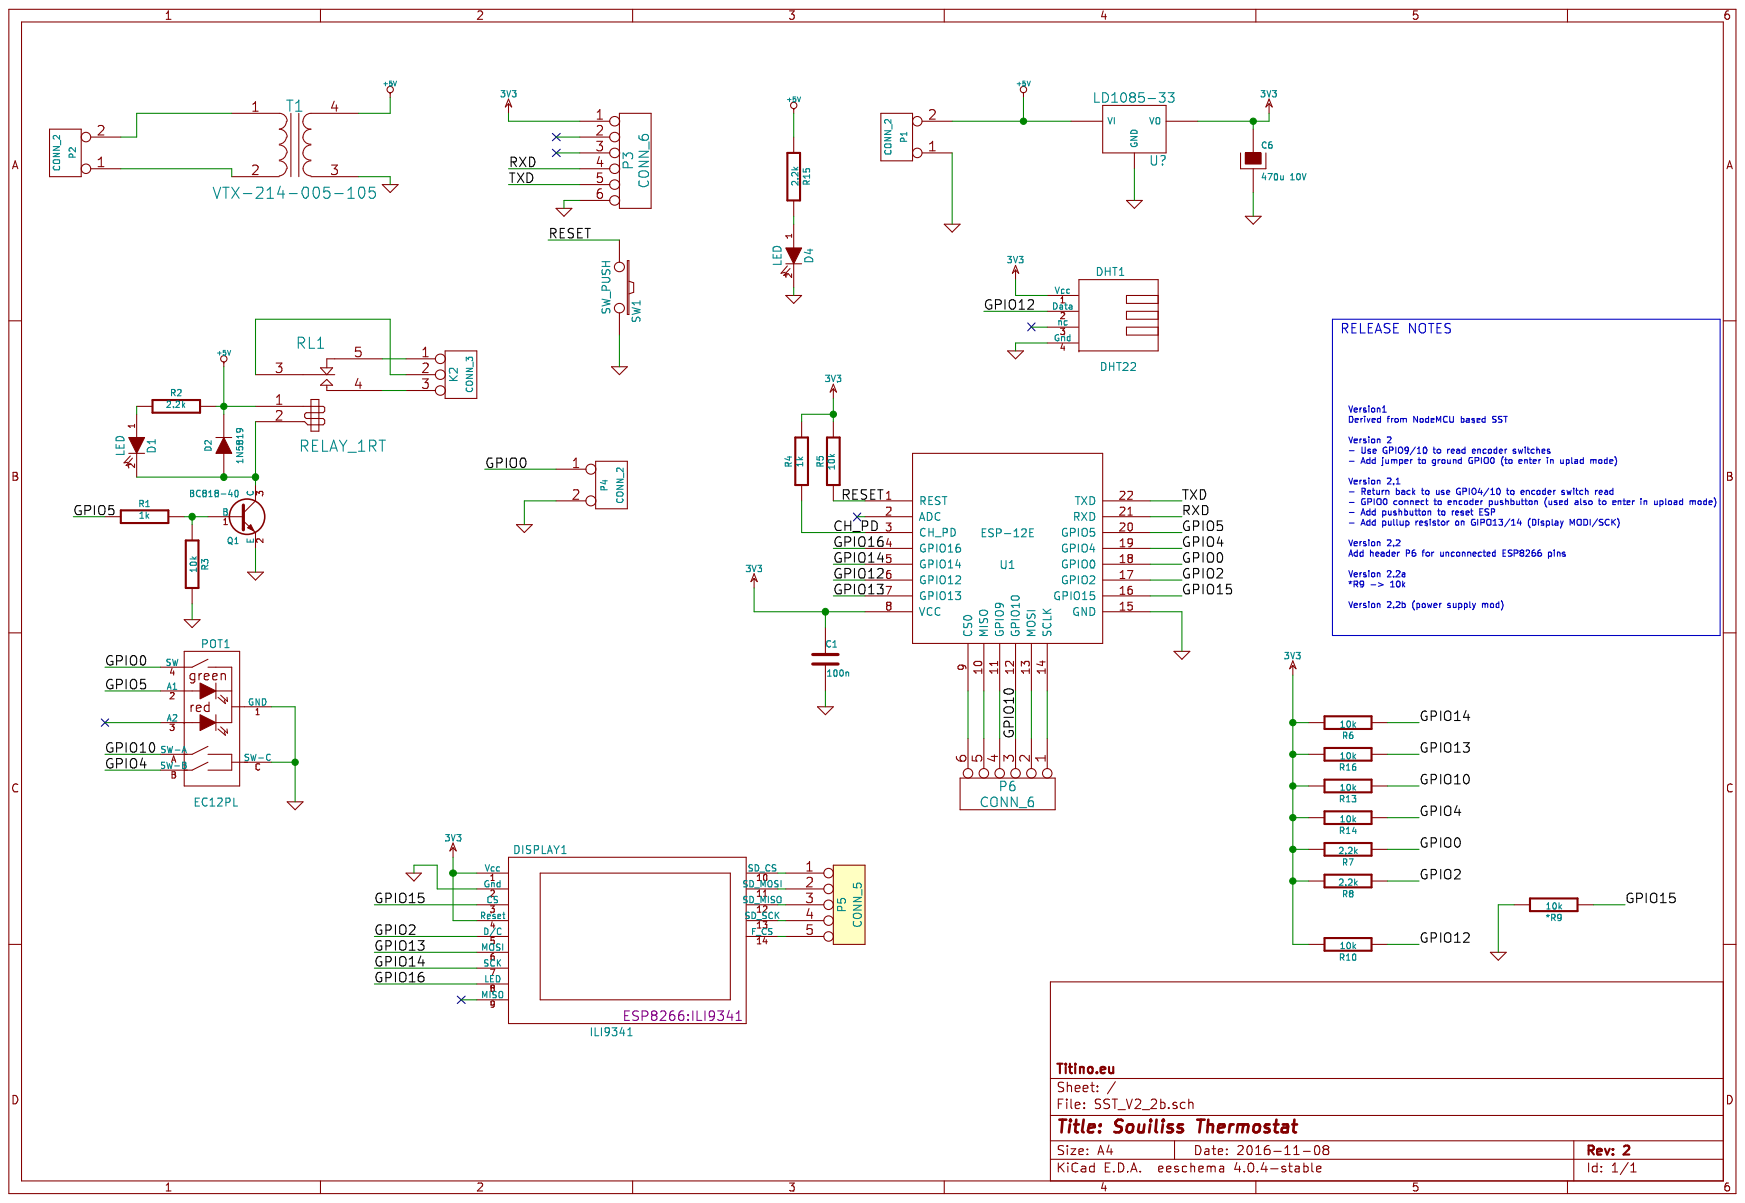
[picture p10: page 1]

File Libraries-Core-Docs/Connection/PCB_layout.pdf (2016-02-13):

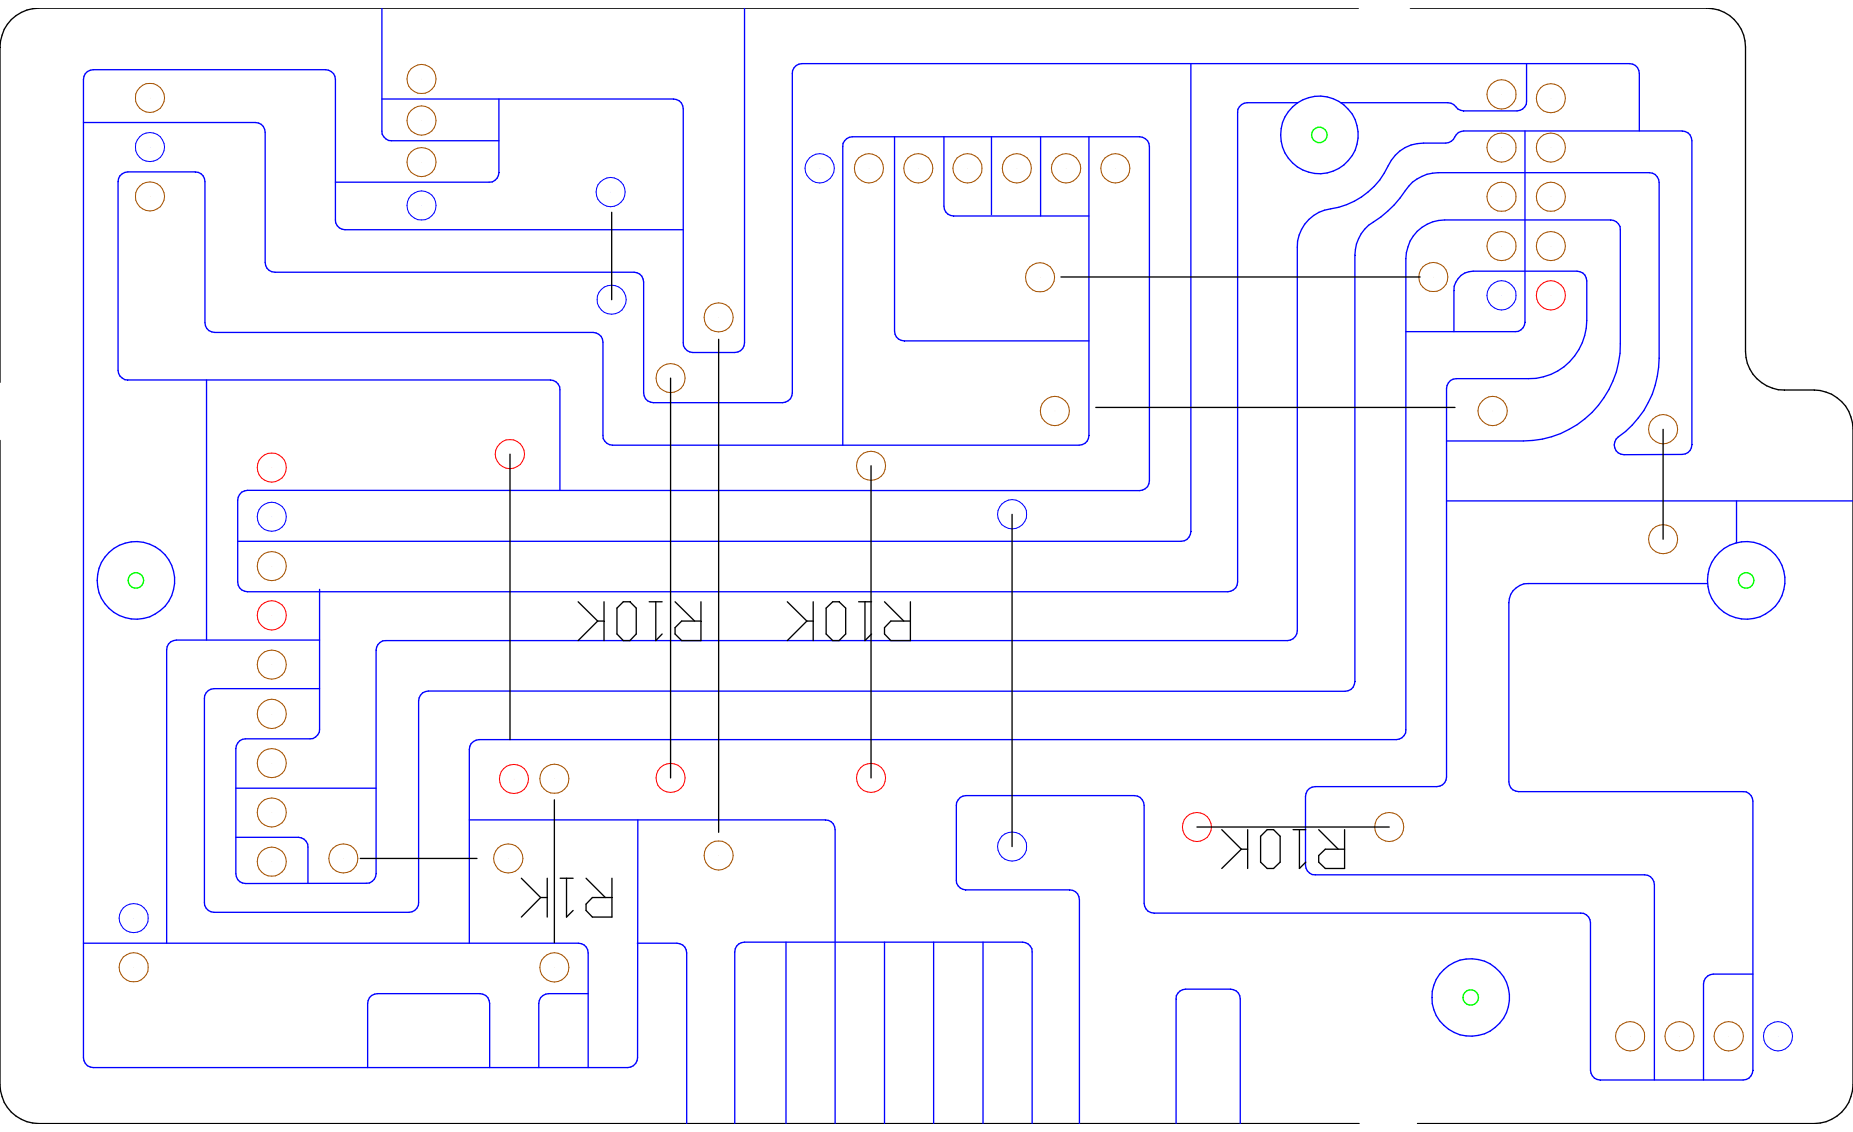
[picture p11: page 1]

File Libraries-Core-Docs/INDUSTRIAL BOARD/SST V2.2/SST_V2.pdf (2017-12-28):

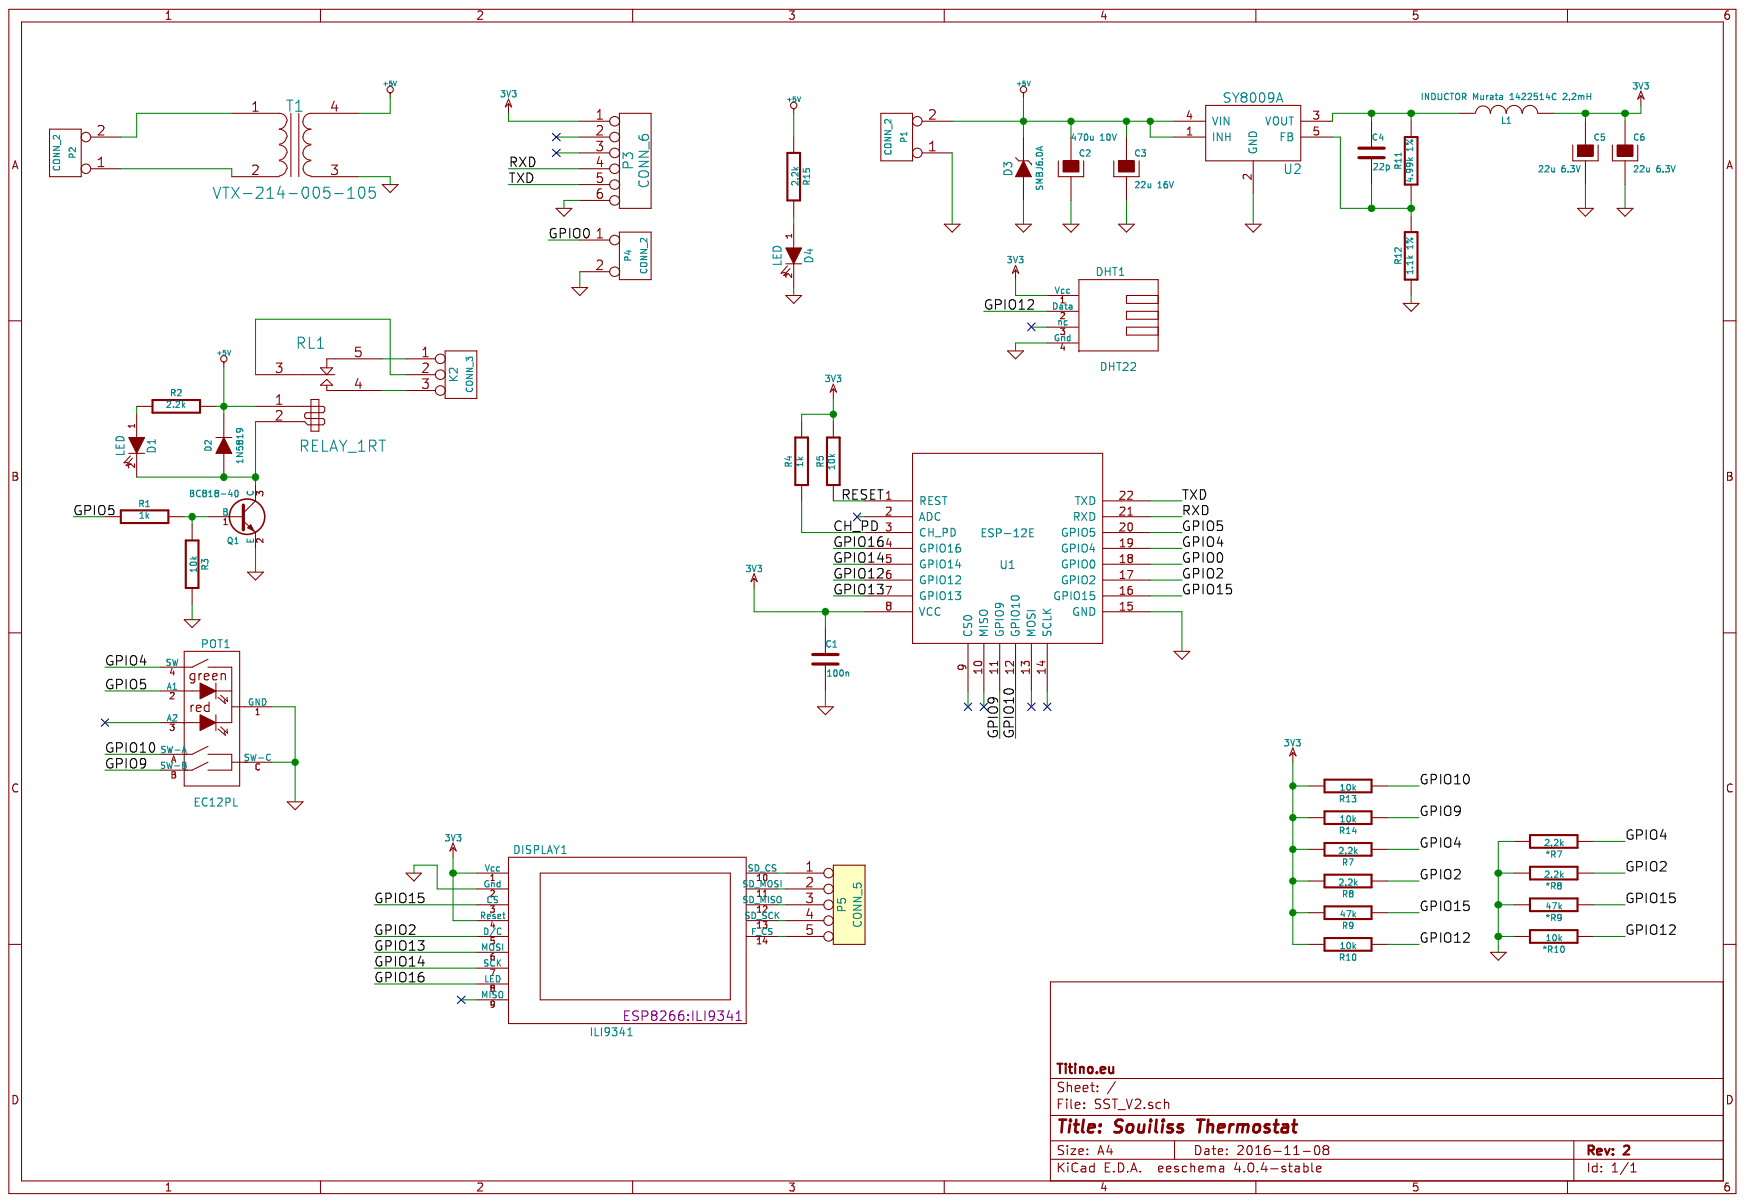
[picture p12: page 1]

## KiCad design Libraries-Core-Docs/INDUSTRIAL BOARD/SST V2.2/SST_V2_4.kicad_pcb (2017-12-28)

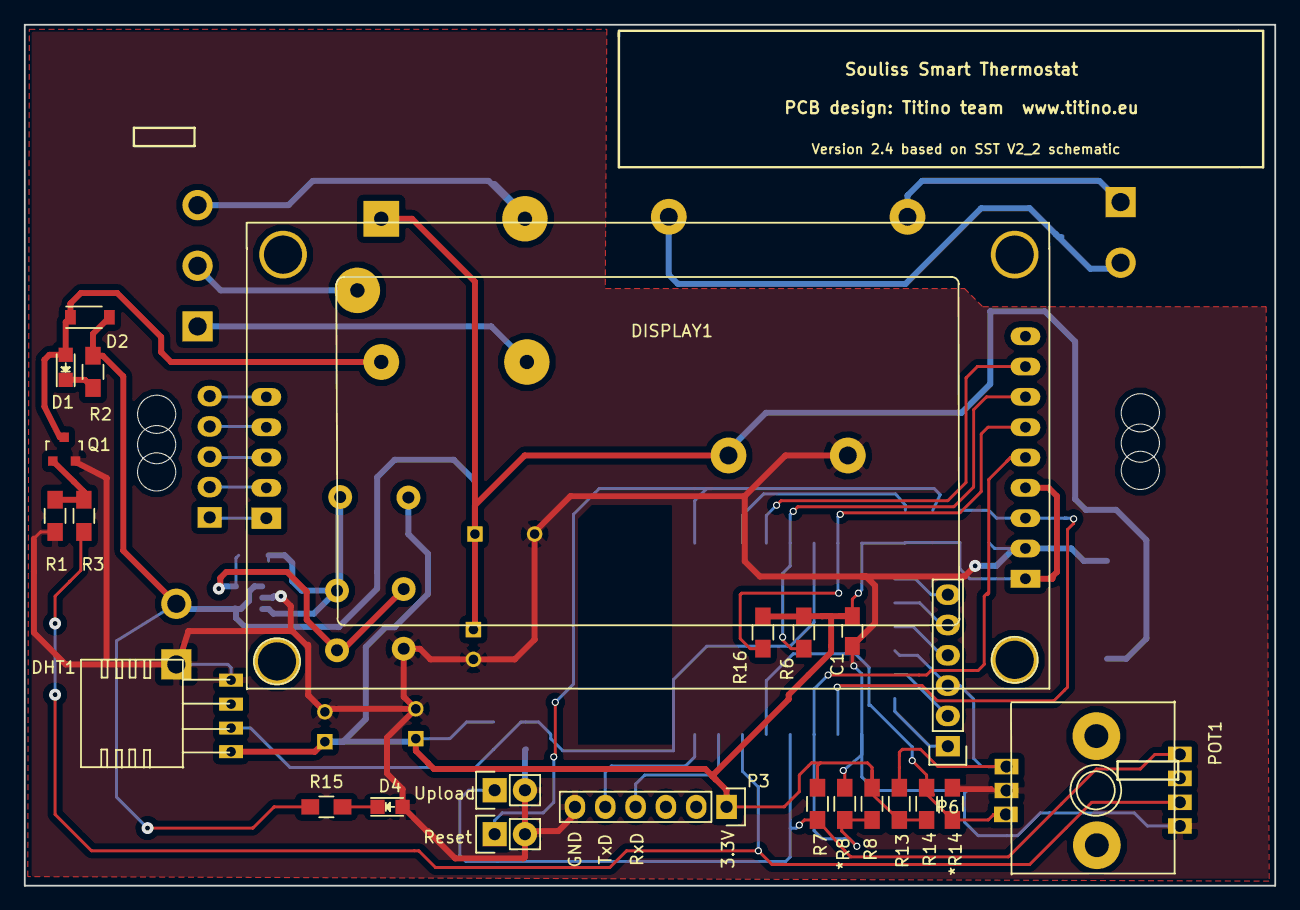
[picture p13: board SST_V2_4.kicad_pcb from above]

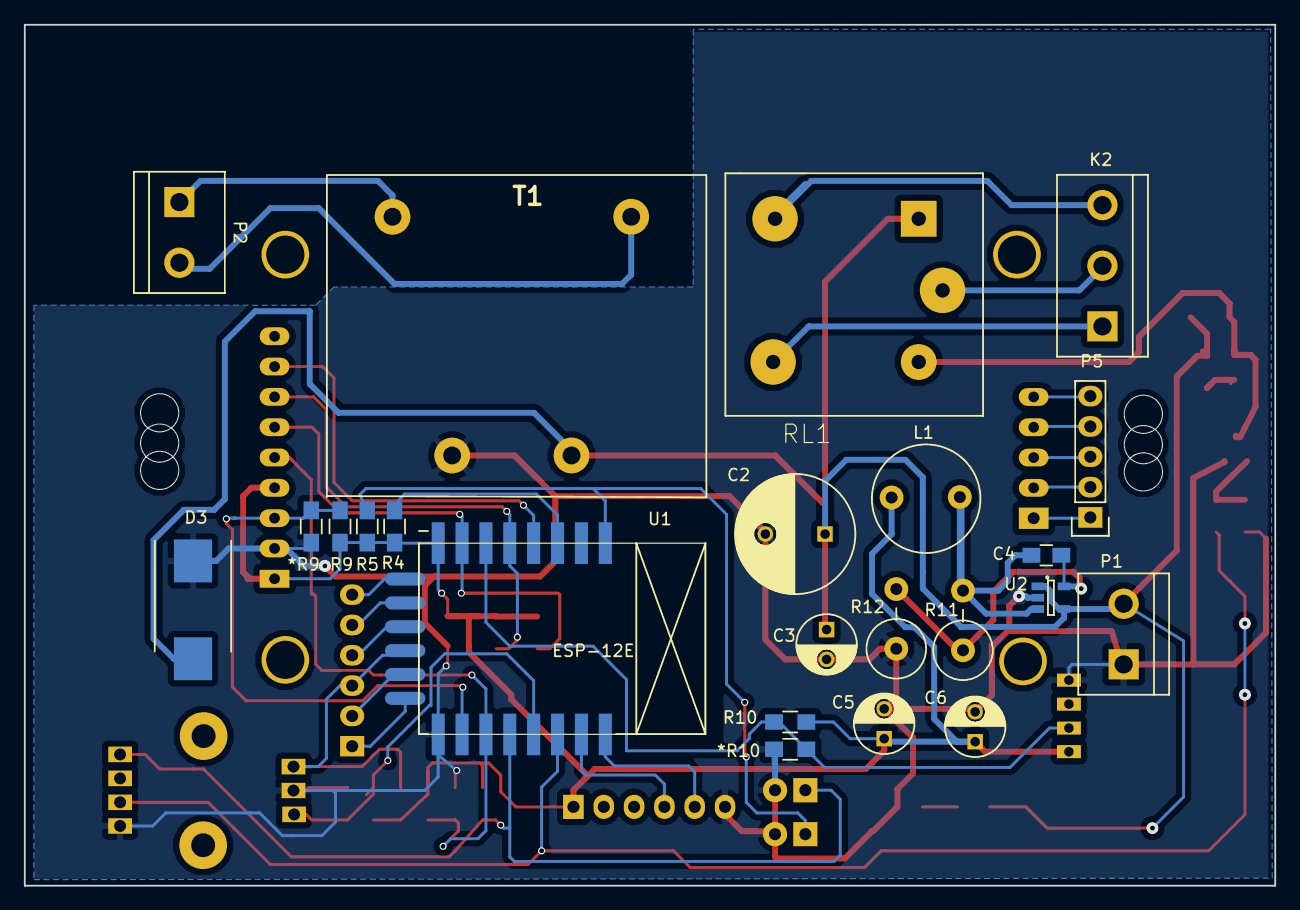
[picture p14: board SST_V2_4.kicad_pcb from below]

Board: 2 copper layers, 104.8 x 72.1 mm, 47 parts (23 on the bottom side), 38 nets.

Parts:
*R8, *R14: 2.2k; R_0805_HandSoldering
*R9: 47k; R_0805_HandSoldering
*R10: 10k; R_0805_HandSoldering
C1: 100n; C_0805_HandSoldering
C2: 470u 10V; C_Radial_D10_L21_P5
C3: 22u 16V; C_Radial_D5_L11_P2.5
C4: 22p; C_0805_HandSoldering
C5, C6: 22u 6.3V; C_Radial_D5_L11_P2.5
D1, D4: LED; LED_0805
D2: 1N5819; SOD-123
D3: SMBJ6.0A; DO-214AB_Handsoldering
DHT1: DHT22
DISPLAY1: ILI9341
K2: CONN_3; bornier3
L1: INDUCTOR Murata 1422514C 2.2mH; Choke_Radial_31mm_2.4mm-Drills_CD_Bobin_Type_No1422455
P1, P2: CONN_2; bornier2
P3, P6: CONN_6; Pin_Header_Straight_1x06
P4: CONN_2; Pin_Header_Straight_1x02
P5: CONN_5; Pin_Header_Straight_1x05
POT1: EC12PL; Encoder_potentiometer
Q1: BC818-40; SOT-23
R1, R4: 1k; R_0805_HandSoldering
R2, R7, R8, R15: 2.2k; R_0805_HandSoldering
R3, R5, R6, R10, R13, R14, R16: 10k; R_0805_HandSoldering
R9: 47k; R_0805_HandSoldering
R11: 4.99k 1%; Resistor_Vertical_RM5mm
R12: 1.1k 1%; Resistor_Vertical_RM5mm
RL1: RELAY_1RT; Relay_1RT
SW1: SW_PUSH; Pin_Header_Straight_1x02
T1: VTX-214-005-105
U1: ESP-12E
U2: SY8009A; SOT-23-5

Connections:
3V3: C1.1, C5.1, C6.1, DHT1.1, DISPLAY1.1, DISPLAY1.4, L1.2, P3.1, R4.2, R5.2, R6.2, R7.2, R8.2, R9.2, R10.2, R13.2, R14.2, R16.2, U1.8
+5V: C2.1, C3.1, D2.2, D3.2, P1.2, R2.2, R15.1, RL1.1, T1.4, U2.1, U2.4
/CH_PD: R4.1, U1.3
/GPIO0: P4.1, POT1.4, R7.1, U1.18
/GPIO2: *R8.1, DISPLAY1.5, R8.1, U1.17
/GPIO4: *R14.1, POT1.B, R14.1, U1.19
/GPIO5: POT1.2, R1.1, U1.20
/GPIO10: P6.3, POT1.A, R13.1, U1.12
/GPIO12: *R10.1, DHT1.2, R10.1, U1.6
/GPIO13: DISPLAY1.6, R16.1, U1.7
/GPIO14: DISPLAY1.7, R6.1, U1.5
/GPIO15: *R9.1, DISPLAY1.3, R9.1, U1.16
/GPIO16: DISPLAY1.8, U1.4
/RESET: R5.1, SW1.1, U1.1
/RXD: P3.4, U1.21
/TXD: P3.5, U1.22
GND: *R8.2, *R9.2, *R10.2, *R14.2, C1.2, C2.2, C3.2, C5.2, C6.2, D3.1, D4.2, DHT1.4, DISPLAY1.2, P1.1, P3.6, P4.2, POT1.1, POT1.C, Q1.2, R3.2, R12.1, SW1.2, T1.3, U1.15, U2.2
unnamed: C4.1, L1.1, R11.2, U2.3
unnamed: C4.2, R11.1, R12.2, U2.5
unnamed: D1.1, R2.1
unnamed: D1.2, D2.1, Q1.3, RL1.2
unnamed: D4.1, R15.2
unnamed: DISPLAY1.10, P5.1
unnamed: DISPLAY1.11, P5.2
unnamed: DISPLAY1.12, P5.3
unnamed: DISPLAY1.13, P5.4
unnamed: DISPLAY1.14, P5.5
unnamed: K2.1, RL1.5
unnamed: K2.2, RL1.3
unnamed: K2.3, RL1.4
unnamed: P2.1, T1.2
unnamed: P2.2, T1.1
unnamed: P6.1, U1.14
unnamed: P6.2, U1.13
unnamed: P6.4, U1.11
unnamed: P6.5, U1.10
unnamed: P6.6, U1.9
unnamed: Q1.1, R1.2, R3.1

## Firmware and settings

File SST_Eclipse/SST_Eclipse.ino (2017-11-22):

/**************************************************************************
  Wi-Fi Smart Thermostat based on Souliss IoT Framework
    -Olimex ESP8266-EVB
    -ILI9341 with SPI connection, via UEXT connector
    -Rotary Encoder with pushbutton & status LED
    -DHT22 Temperature & Humidity Sensor

  This example is only supported on ESP8266.
  Developed by mcbittech & fazioa
***************************************************************************/
// Let the IDE point to the Souliss framework
#include "SoulissFramework.h"

//new customs Souliss_T3n_DeadBand and Souliss_T3n_Hysteresis
#define T3N_DEADBAND_INSKETCH
	#define Souliss_T3n_DeadBand      0.1     // Degrees Deadband
#define T3N_HYSTERESIS_INSKETCH
	#define Souliss_T3n_Hysteresis      0.1     // Degrees Hysteresis

#include <ESP8266WiFi.h>
#include <ESP8266WebServer.h>
#include <ESP8266mDNS.h>
#include <EEPROM.h>
#include "FS.h" //SPIFFS
#include <WiFiUdp.h>
#include <ArduinoOTA.h>
#include <MenuSystem.h>
#include <DHT.h>

// Configure the Souliss framework
#include "bconf/MCU_ESP8266.h"              /** Load the code directly on the ESP8266 */
#include "preferences.h"
#include "multiClick.h"

#if(DYNAMIC_CONNECTION)
#include "conf/RuntimeGateway.h"            // This node is a Peer and can became a Gateway at runtime
#include "conf/DynamicAddressing.h"         // Use dynamically assigned addresses
#include "conf/WEBCONFinterface.h"          // Enable the WebConfig interface
#include "connection_dynamic.h"
#else
#include "conf/IPBroadcast.h"
#include "connection_static.h"
#endif

#define USEEEPROM_INSKETCH
#define USEEEPROM             1


#include "Souliss.h"
#include "encoder.h"
#include "constants.h"
#include "display.h"
#include "display2.h"
#include "displayTopics.h"
#include "language.h"
#include "ntp.h"
#include <TimeLib.h>
#include "menu.h"
#include "crono.h"
#include "read_save.h"
#include "topics.h"
#include "pagesStruct.h"
//*************************************************************************
//*************************************************************************
Page SSTPage;

DHT dht(DHTPIN, DHTTYPE);
float temperature = 0;
float humidity = 0;
float fVal = 0;
float setpoint = 0;
float encoderValue_prec = 0;

//DISPLAY
////////////////////////////////////////////////////////////////////////////////////////////////////////////////
#include <SPI.h>
#include <Arduino.h>
#include "Ucglib.h"

int backLEDvalue = 0;
int backLEDvalueHIGH = BRIGHT_MAX;
int backLEDvalueLOW = BRIGHT_MIN_DEFAULT;
bool FADE = 1;
uint8_t mypayload_len = 0;
uint8_t mypayload[2];
float fTopic_C1_Output;
float fTopic_C2_Output;
float fTopic_C3_Output;
float fTopic_C4_Output;
float fTopic_C5_Output;
float fTopic_C6_Output;

boolean bChildLock = false;

// Menu
MenuSystem* myMenu;

// Use hardware SPI
Ucglib_ILI9341_18x240x320_HWSPI ucg(/*cd=*/ 2 , /*cs=*/ 15);

void EEPROM_Reset() {
  // Erase network configuration parameters from previous use of ZeroConf
  SERIAL_OUT.println("Store_Init");
  Store_Init();
  SERIAL_OUT.println("Store_Clear");
  Store_Clear();
  SERIAL_OUT.println("Store_Commit");
  Store_Commit();
  SERIAL_OUT.println("OK");

  // Print the EEPROM contents, if erase has been succesfull you should see only zeros.
  for (uint16_t i = 0; i < STORE__USABLESIZE; i++)
    SERIAL_OUT.println(Return_8bit(i));

  spiffs_Reset();
  ESP.reset();
}

void subscribeTopics() {
  if (sbscrbdata(TOPIC1, mypayload, &mypayload_len)) {
    float32((uint16_t*) mypayload,  &fTopic_C1_Output);
    SERIAL_OUT.print("TOPIC1: "); SERIAL_OUT.println(fTopic_C1_Output);
  } else if (sbscrbdata(TOPIC2, mypayload, &mypayload_len)) {
    float32((uint16_t*) mypayload,  &fTopic_C2_Output);
    SERIAL_OUT.print("TOPIC2: "); SERIAL_OUT.println(fTopic_C2_Output);
  } else if (sbscrbdata(TOPIC3, mypayload, &mypayload_len)) {
    float32((uint16_t*) mypayload,  &fTopic_C3_Output);
    SERIAL_OUT.print("TOPIC3: "); SERIAL_OUT.println(fTopic_C3_Output);
  } else if (sbscrbdata(TOPIC4, mypayload, &mypayload_len)) {
    float32((uint16_t*) mypayload,  &fTopic_C4_Output);
    SERIAL_OUT.print("TOPIC4: "); SERIAL_OUT.println(fTopic_C4_Output);
  } else if (sbscrbdata(TOPIC5, mypayload, &mypayload_len)) {
    float32((uint16_t*) mypayload,  &fTopic_C5_Output);
    SERIAL_OUT.print("TOPIC5: "); SERIAL_OUT.println(fTopic_C5_Output);
  } else if (sbscrbdata(TOPIC6, mypayload, &mypayload_len)) {
    float32((uint16_t*) mypayload,  &fTopic_C6_Output);
    SERIAL_OUT.print("TOPIC6: "); SERIAL_OUT.println(fTopic_C6_Output);
  }
}


void setSoulissDataChanged() {
  if (data_changed != Souliss_TRIGGED) {

    data_changed = Souliss_TRIGGED;
  }
}

void set_ThermostatModeOn(U8 slot) {
  SERIAL_OUT.println("set_ThermostatModeOn");
  memory_map[MaCaco_OUT_s + slot] |= Souliss_T3n_SystemOn;
  memory_map[MaCaco_OUT_s + slot] &= ~Souliss_T3n_HeatingMode;

  // Trig the next change of the state
  setSoulissDataChanged();
}
void set_ThermostatOff(U8 slot) {
  //memory_map[MaCaco_IN_s + slot] = Souliss_T3n_ShutDown;
  memory_map[MaCaco_OUT_s + SLOT_THERMOSTAT] &= ~ (Souliss_T3n_SystemOn | Souliss_T3n_FanOn1 | Souliss_T3n_FanOn2 | Souliss_T3n_FanOn3 | Souliss_T3n_CoolingOn | Souliss_T3n_HeatingOn);
  setSoulissDataChanged();
}
void set_DisplayMinBright(U8 slot, U8 val) {
  memory_map[MaCaco_OUT_s + slot + 1] = val;
  // Trig the next change of the state

  setSoulissDataChanged();
}

void encoderFunction() {
  encoder();
}

boolean getSoulissSystemState() {
  return memory_map[MaCaco_OUT_s + SLOT_THERMOSTAT] & Souliss_T3n_SystemOn;
}

boolean T_or_H_isNan = false;
boolean bFlagBegin = false;
void getTemp() {
  // Read temperature value from DHT sensor and convert from single-precision to half-precision
  fVal = dht.readTemperature();
  SERIAL_OUT.print("acquisizione Temperature: "); SERIAL_OUT.println(fVal);
  if (!isnan(fVal)) {
    temperature = fVal; //memorizza temperatura se non è Not A Number
    //Import temperature into T31 Thermostat
    ImportAnalog(SLOT_THERMOSTAT + 1, &temperature);
    ImportAnalog(SLOT_TEMPERATURE, &temperature);
  } else {
    bFlagBegin = true;
  }

  // Read humidity value from DHT sensor and convert from single-precision to half-precision
  fVal = dht.readHumidity();
  SERIAL_OUT.print("acquisizione Humidity: "); SERIAL_OUT.println(fVal);
  if (!isnan(fVal)) {
    humidity = fVal;
    ImportAnalog(SLOT_HUMIDITY, &humidity);
  } else {
    bFlagBegin = true;
  }

  if ( bFlagBegin) {
    //if DHT fail then try to reinit
    dht.begin();
    SERIAL_OUT.println(" dht.begin();");
  }
}

void initScreen() {
  ucg.clearScreen();
  SERIAL_OUT.println("clearScreen ok");
  if (getLayout1()) {
    SERIAL_OUT.println("HomeScreen Layout 1");

    display_layout1_HomeScreen(ucg, temperature, humidity, setpoint, getSoulissSystemState(), bChildLock);
    getTemp();
  }
  else if (getLayout2()) {
    SERIAL_OUT.println("HomeScreen Layout 2");
    getTemp();
    display_layout2_HomeScreen(ucg, temperature, humidity, setpoint);
    display_layout2_print_circle_white(ucg);
    display_layout2_print_datetime(ucg);
    if (ACTIVATETOPICSPAGE == 1) {
      alwaysdisplayTopicsHomePageLayout2(ucg, fTopic_C1_Output, fTopic_C2_Output, fTopic_C3_Output, fTopic_C4_Output, fTopic_C5_Output, fTopic_C6_Output);
    }
    display_layout2_print_circle_black(ucg);
    yield();
    display_layout2_print_circle_green(ucg);
  }
}
void setSetpoint(float setpoint) {
  //SERIAL_OUT.print("Away: ");SERIAL_OUT.println(memory_map[MaCaco_OUT_s + SLOT_AWAY]);
  if (memory_map[MaCaco_OUT_s + SLOT_AWAY]) {
    //is Away

  } else {
    //is not Away
  }
  Souliss_HalfPrecisionFloating((memory_map + MaCaco_OUT_s + SLOT_THERMOSTAT + 3), &setpoint);
}
void bright(int lum) {
  int val = ((float)lum / 100) * 1023;
  if (val > 1023) val = 1023;
  if (val < 0) val = 0;
  analogWrite(BACKLED, val);
}

void publishHeating_ON_OFF() {
  //code from Souliss_nDigOut(...
  //nDigOut(RELE, Souliss_T3n_HeatingOn, SLOT_THERMOSTAT);    // Heater

  if (memory_map[MaCaco_OUT_s + SLOT_THERMOSTAT] & Souliss_T3n_HeatingOn)
    pblshdata(SST_HEAT_ONOFF, &HEAT_ON, 1);
  else
    pblshdata(SST_HEAT_ONOFF, &HEAT_OFF, 1);
}



void setup()
{

  SERIAL_OUT.begin(115200);

  //SPIFFS
  /////////////////////////////////////////////////////////////////////////////////////////////////////////
  SPIFFS.begin();
  File  sst_spiffs_verifica = SPIFFS.open("/sst_settings.json", "r");
  if (!sst_spiffs_verifica) {
    Serial.println(" ");
    Serial.println("Non riesco a leggere sst_settings.json! formatto la SPIFFS...");
    SPIFFS.format();
    Serial.println("Spiffs formatted");
    ReadAllSettingsFromPreferences();
    ReadCronoMatrixSPIFFS();
  }
  else
  {
    ReadAllSettingsFromSPIFFS();
    ReadCronoMatrixSPIFFS();
    backLEDvalueLOW = getDisplayBright();
  }

  //DISPLAY INIT
  /////////////////////////////////////////////////////////////////////////////////////////////////////////
  ucg.begin(UCG_FONT_MODE_SOLID);

  //SPI Frequency
  SPI.setFrequency(80000000);

  ucg.setColor(0, 0, 0);
  ucg.setRotate90();
  //BACK LED
  /////////////////////////////////////////////////////////////////////////////////////////////////////////
  //digitalWrite(BACKLED, HIGH);
  bright(BRIGHT_MAX);
  pinMode(BACKLED, OUTPUT);                     // Background Display LED

  display_print_splash_screen(ucg);
  Initialize();

#if(DYNAMIC_CONNECTION)
  DYNAMIC_CONNECTION_Init();
#else
#if(DHCP_OPTION)
  STATIC_CONNECTION_Init_DHCP();
#else
  STATIC_CONNECTION_Init_STATICIP();
#endif
#endif


  //*************************************************************************
  //*************************************************************************
  Set_T52(SLOT_TEMPERATURE);
  Set_T53(SLOT_HUMIDITY);
  Set_T19(SLOT_BRIGHT_DISPLAY);
  Set_T11(SLOT_AWAY);

  //set default mode
  Set_Thermostat(SLOT_THERMOSTAT);
  set_ThermostatModeOn(SLOT_THERMOSTAT);
  set_DisplayMinBright(SLOT_BRIGHT_DISPLAY, backLEDvalueLOW);

  // Define output pins
  pinMode(RELE, OUTPUT);    // Heater
  dht.begin();

  //ENCODER
  /////////////////////////////////////////////////////////////////////////////////////////////////////////
  pinMode (ENCODER_PIN_A, INPUT_PULLUP);
  pinMode (ENCODER_PIN_B, INPUT_PULLUP);
  attachInterrupt(digitalPinToInterrupt(ENCODER_PIN_A), encoderFunction, CHANGE);
  attachInterrupt(digitalPinToInterrupt(ENCODER_PIN_B), encoderFunction, CHANGE);
  // SWITCH ENCODER
  //digitalWrite(BACKLED, HIGH);
  bright(BRIGHT_MAX);
  pinMode(ENCODER_SWITCH, INPUT);

  //NTP
  /////////////////////////////////////////////////////////////////////////////////////////////////////////
  initNTP();
  delay(1000);
  //*************************************************************************
  //*************************************************************************

  //MENU
  /////////////////////////////////////////////////////////////////////////////////////////////////////////
  initMenu();
  myMenu = getMenu();


  // Init the OTA
  // Set Hostname.
  String hostname(HOSTNAME);
  hostname += String(ESP.getChipId(), HEX);
  SERIAL_OUT.print("set OTA hostname: "); SERIAL_OUT.println(hostname);
  ArduinoOTA.setHostname((const char *)hostname.c_str());
  ArduinoOTA.begin();

  // Init HomeScreen
  initScreen();
}

void loop()
{
  EXECUTEFAST() {
    UPDATEFAST();

    switch (SSTPage.actualPage) {
      case PAGE_MENU :
        if (getMenuEnabled() && !bChildLock) {
          //Bright high if menu enabled
          FADE = 1;
          //Menu Command Section
          if (getEncoderValue() != encoderValue_prec)
          {
            if (getEncoderValue() > encoderValue_prec) {
              //Menu DOWN
              myMenu->next();
            } else {
              //Menu UP
              myMenu->prev();
            }
            printMenuMove(ucg);
            encoderValue_prec = getEncoderValueSlow();
          }
        }
        if (getMenuEnabled() && !digitalRead(ENCODER_SWITCH)) {
          //IF MENU ENABLED
          myMenu->select(true);
          ucg.clearScreen();
          printMenu(ucg);
        }

    }

    SHIFT_50ms(0) {
      //set point attuale
      setpoint = Souliss_SinglePrecisionFloating(memory_map + MaCaco_OUT_s + SLOT_THERMOSTAT + 3);
      //Stampa il setpoint solo se il valore dell'encoder è diverso da quello impostato nel T31
      switch (SSTPage.actualPage) {
        case PAGE_MENU :
          if (!getMenuEnabled()) {
            SSTPage.actualPage = PAGE_HOME;
            initScreen();
            setUIChanged();
          }
          break;
        case PAGE_CRONO :
          break;
        default:
          if (arrotonda(getEncoderValueSlow()) != arrotonda(encoderValue_prec) && !bChildLock) {
            FADE = 1;
            //TICK TIMER
            timerDisplay_setpoint_Tick();
            //SETPOINT PAGE ////////////////////////////////////////////////////////////////

            if (getLayout1()) {
              SERIAL_OUT.println("display_setpointPage - layout 1");
              display_layout1_background(ucg, arrotonda(getEncoderValueSlow()) - arrotonda(setpoint));
			  
              display_layout1_setpointPage(ucg, getEncoderValueSlow(), temperature, humidity, getSoulissSystemState());
            }
            else if (getLayout2()) {
              SERIAL_OUT.println("display_setpointPage - layout 2");
              display_layout2_Setpoint(ucg, getEncoderValueSlow(), getSoulissSystemState(), bChildLock);
            }
          }
          encoderValue_prec = getEncoderValue();
          break;
      }
    }
    SHIFT_50ms(3) {
      Logic_T19(SLOT_BRIGHT_DISPLAY);
      Logic_T11(SLOT_AWAY);
    }

    SHIFT_110ms(0) {
      if (!getMenuEnabled()) {
        if (timerDisplay_setpoint()) {
          //timeout scaduto
          display_layout1_background_black(ucg);
          setEncoderValue(setpoint);
        } else {
          //timer non scaduto. Memorizzo
          setpoint = getEncoderValueSlow();
          //memorizza il setpoint nel T31
          setSetpoint(setpoint);

          // Trig the next change of the state
          setSoulissDataChanged();
        }
      }
    }


    SHIFT_110ms(4) {
      //SWITCH ENCODER
      //Al click in base al valore attuale di SSTPage, si imposta la pagina successiva

      int b = checkButton(ENCODER_SWITCH);
      if (b == 2) SERIAL_OUT.println("Double Click");
      if (b == 3) {
        SERIAL_OUT.println("Hold");
        bChildLock = !bChildLock;
        SERIAL_OUT.print("Child Lock: "); SERIAL_OUT.println(bChildLock);
        ucg.clearScreen();
        setUIChanged();
        if (getLayout2()) {
          //Reinizializzo la Home per mostrare subito il cambio stato locked/unlocked e non aspettare il refresh
          initScreen();
        }
      }
      if (b == 4) SERIAL_OUT.println("Long Hold");

      if (b == 1) {
        switch (SSTPage.actualPage) {
          case PAGE_HOME:
            if (ACTIVATETOPICSPAGE > 0) {
              SERIAL_OUT.println("from PAGE_HOME to PAGE_TOPICS1");
              SSTPage.actualPage = PAGE_TOPICS1;
              setUIChanged();
            } else {
              SERIAL_OUT.println("from PAGE_HOME to PAGE_MENU");
              SSTPage.actualPage = PAGE_MENU;
              setUIChanged();
              ucg.clearScreen();
              setMenuEnabled();
              //se system and UI changed
              setUIChanged();
              SERIAL_OUT.println("Print Menu");
              printMenu(ucg);
            }
            break;
          case PAGE_TOPICS1:
            if (TOPICSPAGESNUMBER == 1) {
              SERIAL_OUT.println("from PAGE_TOPICS1 to PAGE_MENU");
              SSTPage.actualPage = PAGE_MENU;

              setUIChanged();
              ucg.clearScreen();
              setMenuEnabled();

              SERIAL_OUT.println("Print Menu");
              printMenu(ucg);
            }
            else if (TOPICSPAGESNUMBER == 2) {
              SERIAL_OUT.println("from PAGE_TOPICS1 to PAGE_TOPICS2");
              SSTPage.actualPage = PAGE_TOPICS2;
              setUIChanged();
            }
            break;
          case PAGE_TOPICS2:
            SERIAL_OUT.println("from PAGE_TOPICS2 to PAGE_MENU");
            SSTPage.actualPage = PAGE_MENU;
            setUIChanged();
            ucg.clearScreen();
            setMenuEnabled();
            //se system and UI changed
            setUIChanged();
            SERIAL_OUT.println("Print Menu");
            printMenu(ucg);
            break;
          case PAGE_MENU:

            break;
          case PAGE_CRONO:

            break;
        }
      } else {
        //se progCrono è attivo allora passo alla pagina CRONO
        if (getProgCrono()) {
          SSTPage.actualPage = PAGE_CRONO;
          byte menu;
          SERIAL_OUT.println("Crono");
          ucg.clearScreen();
          drawCrono(ucg);
          SERIAL_OUT.println("drawCrono ok");
          menu = 1;
          //save encoder value before crono programmation
          setpoint = getEncoderValueSlow();
          while (menu == 1 && exitmainmenu() == 0) {
            setDay(ucg);
            drawBoxes(ucg);
            setBoxes(ucg);
            if (exitmainmenu())
            {
              SERIAL_OUT.println("from PAGE_CRONO to PAGE_HOME");
              SSTPage.actualPage = PAGE_HOME;
              initScreen();
              setUIChanged();
              menu = 0;
            }
	  yield();	  
          }
          //restore encoder value
          setEncoderValue(setpoint);
        }
      }
    }

    SHIFT_210ms(0) {
      //FADE
      if (FADE == 0) {
        //Raggiunge il livello di luminosità minima, che può essere variata anche da SoulissApp
        if ( backLEDvalue != backLEDvalueLOW) {
          if ( backLEDvalue > backLEDvalueLOW) {
            backLEDvalue -= BRIGHT_STEP_FADE_OUT;
          } else {
            backLEDvalue += BRIGHT_STEP_FADE_OUT;
          }
          bright(backLEDvalue);
        }
      } else  if (FADE == 1 && backLEDvalue < backLEDvalueHIGH) {
        backLEDvalue +=  BRIGHT_STEP_FADE_IN;
        bright(backLEDvalue);
      }
    }

    SHIFT_210ms(2) {   // We process the logic and relevant input and output
      // Update topics in layout2 home page
      if (getLayout2()) {
        if (ACTIVATETOPICSPAGE == 1 && SSTPage.actualPage == PAGE_HOME) {
          displayTopicsHomePageLayout2(ucg, fTopic_C1_Output, fTopic_C2_Output, fTopic_C3_Output, fTopic_C4_Output, fTopic_C5_Output, fTopic_C6_Output);
        }
      }
    }

    FAST_510ms() {
      //*************************************************************************
      //*************************************************************************
      Logic_Thermostat(SLOT_THERMOSTAT);
            
      // Start the heater and the fans
      nDigOut(RELE, Souliss_T3n_HeatingOn, SLOT_THERMOSTAT);    // Heater


      // We are not handling the cooling mode, if enabled by the user, force it back
      // to disable
      if (mOutput(SLOT_THERMOSTAT) & Souliss_T3n_CoolingOn)
        mOutput(SLOT_THERMOSTAT) &= ~Souliss_T3n_CoolingOn;

      //if menu disabled and nothing changed
      if (SSTPage.actualPage != PAGE_MENU) {
        if (!getSystemChanged()) {
          if (getLocalSystem() != getSoulissSystemState())
            setSystem(getSoulissSystemState());
        }
      }

      //*************************************************************************
      //*************************************************************************

      Logic_T52(SLOT_TEMPERATURE);
      Logic_T53(SLOT_HUMIDITY);
    }

    FAST_710ms() {
      //HOMESCREEN ////////////////////////////////////////////////////////////////
      ///update homescreen only if menu exit
      if (getSystemChanged()) {
        //EXIT MENU - Actions
        //write min bright on T19
        memory_map[MaCaco_OUT_s + SLOT_BRIGHT_DISPLAY + 1] = getDisplayBright();
        SERIAL_OUT.print("Set Display Bright: "); SERIAL_OUT.println(memory_map[MaCaco_OUT_s + SLOT_BRIGHT_DISPLAY + 1]);

        //write system ON/OFF
        if (getLocalSystem()) {

          //ON
          SERIAL_OUT.println("Set system ON ");
          set_ThermostatModeOn(SLOT_THERMOSTAT);        // Set System On

        } else {

          //OFF
          SERIAL_OUT.println("Set system OFF ");
          set_ThermostatOff(SLOT_THERMOSTAT);
        }
        memory_map[MaCaco_IN_s + SLOT_THERMOSTAT] = Souliss_T3n_RstCmd;          // Reset
        // Trig the next change of the state
        setSoulissDataChanged();
        SERIAL_OUT.println("Init Screen");
        setUIChanged();
        initScreen();

        resetSystemChanged();
      }
    }

    FAST_2110ms() {

      //Crono Status in Layout 2
      if (getCrono() && getLayout2() && SSTPage.actualPage == PAGE_HOME ) {

        if (checkCronoStatus(ucg) == 0) //OFF
        {
          ucg.setColor(0, 0, 0);       // black
          ucg.drawDisc(156, 50, 5, UCG_DRAW_ALL);
          ucg.drawDisc(165, 62, 6, UCG_DRAW_ALL);
          ucg.drawDisc(173, 77, 7, UCG_DRAW_ALL);
          ucg.drawDisc(179, 95, 8, UCG_DRAW_ALL);
        }

        if (checkCronoStatus(ucg) == 1) //ECO
        {
          ucg.setColor( 102, 255, 0);       // Verde
          ucg.drawDisc(156, 50, 5, UCG_DRAW_ALL);
          ucg.setColor(0, 0, 0);       // black
          ucg.drawDisc(165, 62, 6, UCG_DRAW_ALL);
          ucg.drawDisc(173, 77, 7, UCG_DRAW_ALL);
          ucg.drawDisc(179, 95, 8, UCG_DRAW_ALL);
        }
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

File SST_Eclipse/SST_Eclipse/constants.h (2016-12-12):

#include <Arduino.h>
#include <ESP8266WiFi.h>

#define VERSION "v 1.2"
#define HOSTNAME "SST-Thermostat-OTA-" ///< Hostename. The setup function adds the Chip ID at the end.
//DHT22
////////////////////////////////////////////////////////////////////////////////////////////////////////////////
#define DHTPIN 12
#define DHTTYPE DHT22

//ENCODER
///////////////////////////////////////////////////////////////////////////////////////////////////////////////
#define ENCODER_PIN_A   3
#define ENCODER_PIN_B   4
#define ENCODER_SWITCH  0

//DISPLAY
/////////////////////////////////////////////////////////////////////////////////////////////////////////
#define TFT_DC 2
#define TFT_CS 15

//SLOT
////////////////////////////////////////////////////////////////////////////////////////////////////////////////
#define SLOT_THERMOSTAT         0
#define SLOT_TEMPERATURE        5     // This is the memory slot used for the execution of the logic in network_address1
#define SLOT_HUMIDITY           7     // This is the memory slot used for the execution of the logic
#define SLOT_BRIGHT_DISPLAY     9
#define SLOT_AWAY               11


//T31 Commands
#define Souliss_T3n_InSetPoint      0x01
#define Souliss_T3n_OutSetPoint     0x02
#define Souliss_T3n_AsMeasured      0x03
#define Souliss_T3n_Cooling         0x04
#define Souliss_T3n_Heating         0x05
#define Souliss_T3n_FanOff          0x06
#define Souliss_T3n_FanLow          0x07
#define Souliss_T3n_FanMed          0x08
#define Souliss_T3n_FanHigh         0x09
#define Souliss_T3n_FanAuto         0x0A
#define Souliss_T3n_FanManual       0x0B
#define Souliss_T3n_SetTemp         0x0C
#define Souliss_T3n_ShutDown        0x0D

//Souliss Commands
#define Souliss_TRIGGED             0x01


//PIN
////////////////////////////////////////////////////////////////////////////////////////////////////////////////
// **** Define here the right pin for your ESP module ****
#define RELE     5
#define BACKLED  16


//TIMER DISPLAY
#define TIMER_DISPLAY_SETPOINT 4000

//AWAY
#define TEMP_MINUS 1

#define SERIAL_OUT Serial

//FONT
////////////////////////////////////////////////////////////////////////////////////////////////////////////////
//#define FONT_BIG ucg_font_inb63_mn
//#define FONT_BIG ucg_font_inb46_mr
//#define FONT_BIG_MIN_50_PERCENT ucg_font_inb33_mr
#define FONT_BIG ucg_font_inb53_mn
#define FONT_BIG_MIN_50_PERCENT ucg_font_inb24_mr

#define FONT_BIG_SCALE2x2             1     //1 Scale - 0 Don't Scale
#define FONT_SMALL ucg_font_inb16_mr
#define FONT_SMALL_CENTIGRAD ucg_font_helvB10_hr
#define FONT_SMALLEST ucg_font_4x6_mf
#define FONT_SPLASH_SCREEN ucg_font_inb21_mr

#define FONT_SHIFT_POSITION_TO_SX_CENTIGRAD 5

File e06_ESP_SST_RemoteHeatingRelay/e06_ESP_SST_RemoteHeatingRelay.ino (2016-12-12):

#include "SoulissFramework.h"
#include <ESP8266mDNS.h>
#include <EEPROM.h>
#include "bconf/MCU_ESP8266.h"              // Load the code directly on the ESP8266
#include "conf/IPBroadcast.h"

// **** Define the WiFi name and password ****
#define WIFICONF_INSKETCH
#define WiFi_SSID               "***toConfigure***"
#define WiFi_Password           "***toConfigure***"


// Include framework code and libraries
#include <ESP8266WiFi.h>
#include "Souliss.h"
#include "topics.h"
//*************************************************************************
// Define the network configuration according to your router settingsuration according to your router settings
// and the other on the wireless oneless one
#define peer_address  0xAB31
#define myvNet_subnet 0xFF00
#define myvNet_supern 0xAB10

//*************************************************************************

#define SLOT            0
#define RELE            5
#define PIN_ACTIVITYLED 4
bool bActivityLed=LOW;

uint8_t mypayload_len = 0;
U8 mypayload;

void setup()
{
  delay(10000);
  Initialize();
  //  Serial.print("Get IP Address: ");
  GetIPAddress();
  //Serial.println(WiFi.localIP());
  SetAddress(peer_address, myvNet_subnet, myvNet_supern);          // Address on the wireless interface

  // Define output pins
  pinMode(RELE, OUTPUT);    // Relè
   pinMode(PIN_ACTIVITYLED, OUTPUT);    // Activity Led
}

void loop()
{
  EXECUTEFAST() {
    UPDATEFAST();

    FAST_50ms() {
      subcriptionHeating_ON_OFF();
    }
    FAST_2110ms(){
      bActivityLed=!bActivityLed;
      digitalWrite(PIN_ACTIVITYLED, bActivityLed);
    }

    FAST_PeerComms();
  }
}

void subcriptionHeating_ON_OFF() {
  if (sbscrbdata(SST_HEAT_ONOFF, &mypayload, &mypayload_len)) {
    if (mypayload == HEAT_ON)
      digitalWrite(RELE, HIGH);
    else
      digitalWrite(RELE, LOW);
  }
}

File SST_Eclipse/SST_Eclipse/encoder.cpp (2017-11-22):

//ENCODER
////////////////////////////////////////////////////////////////////////////////////////////////////////////////
#include <Arduino.h>
#include "constants.h"

volatile int encoder0Pos = 220;
volatile float encoderValue = 20.0;
int encoder_PinALast = LOW;



void encoder() {
    int MSB = digitalRead(ENCODER_PIN_B); //MSB = most significant bit
    int LSB = digitalRead(ENCODER_PIN_A); //LSB = least significant bit

    int encoded = (MSB << 1) | LSB; //converting the 2 pin value to single number
    int sum  = (encoder_PinALast << 2) | encoded; //adding it to the previous encoded value

    if (sum == 0b1101 || sum == 0b0100 || sum == 0b0010 || sum == 0b1011) encoder0Pos ++;
    if (sum == 0b1110 || sum == 0b0111 || sum == 0b0001 || sum == 0b1000) encoder0Pos --;
  
    encoder_PinALast = encoded; //store this value for next time
    encoderValue = encoder0Pos / 10.0;

}

void setEncoderValue(float val) {
  encoder0Pos = val * 10;
  encoderValue = val;
}

float getEncoderValue() {
  return encoderValue;
}

float getEncoderValueSlow() {
  return encoderValue / 2.0;
}

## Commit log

2015-09-16 Start from Souliss - Web Configuration Inclusion of ILI9341 libraries and code for encoder.
    TO DO:
    - print on display
    - menu
2015-09-17 Display setpoin with old font ok There is a problem with T31
    [display.cpp, e03_ESP8266_SST_webconf.ino]
2015-09-23 revolution on library side
    e04_ESP8266_SST_beta working with souliss framework & new library,
    require replacement of ESP core
    [display.cpp, e02_ESP8266_smart_thermostat_beta.ino, e03_ESP8266_SST_webconf.ino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]
2015-09-23 added LED backlite regulation with PWM & analogWrite
2015-09-28 font ok TODO: enhance encoder
2015-09-28 added NTP & refresh temperature in SLOW110s
2015-09-28 Flavio Splash screen Rallentati cicli disegno, per avere priorità sull'encoder Da migliorare
2015-09-28 Interrupt HW on encoder
2015-09-28 led backlight correction
2015-09-28 encoder with HW interrupt
2015-09-28 Encoder improvement
2015-09-28 new routine for encoder
2015-09-30 trend Status,Fading LEDbacklight, NTP correction
    [e04_ESP8266_SST_beta_circle.ino]
2015-10-01 Add T19 for dimmer display led 100% on setpoint page
2015-10-02 Add layout connection
    [SST.sch]
2015-10-08 work in progress. BigChar position To review (do not work) Structure for multiple layouts ok
    [display.cpp, e05_ESP8266_SST_webconf.ino]
2015-10-27 Added power info
2015-10-29 Mod to LAYOUT_1 Click to clean screen and print menu on serial monitor
2015-12-07 changed directories structures
    [SST.sch]
2015-12-07 Problem with SPI Frequency. Ok
    [e05_ESP8266_SST_webconf.ino]
2015-12-27 Recovery scheme folder file
    [SST.sch]
2016-01-19 Code restructuration
    [SST.sch]
2016-02-04 Added serial.print for debug
2016-02-04 Increase SPI speed Delete debug line Beta Testing version for NTP & Layout2 issue
    [constants.h, e05_ESP8266_SST_webconf.ino, encoder.cpp]
2016-02-04 Add Flavio files
    [SST.sch]
2016-02-11 Added PCB layout
2016-02-16 Crono DEV - DarioCdj mod correction CRONO UNDER DEVELOPMENT
    [crono.cpp, display.cpp, e05_ESP8266_SST_webconf.ino]
2016-02-16 fix 4 setpoint bar
    [crono.cpp]
2016-02-17 Inserimento di varie opzioni nel file preferences.h Possibilità di decidere, in fase di compilazione, se usare il collegamento con SSID ed indirizzi IP e VNet statici, oppure la modalità webconf
2016-02-21 eeprom correction + chrono read/save data from eeprom
    [constants.h, crono.cpp, e05_ESP8266_SST_webconf.ino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]
2016-02-23 Hook crono data from NTP Time -beta minor bugfixes(eeprom float setpoint, colour, days sequence)
    [crono.cpp, e05_ESP8266_SST_webconf.ino, encoder.cpp]
2016-02-24 It compile but not work with IDE 1.6.5 and 1.6.7, CORE Stable 2.0
    [e05_ESP8266_SST_webconf.ino]
2016-02-29 days + save visualization fix
    [crono.cpp]
2016-02-29 Added static IP option(thanks to Dariocdj) Fixed menù navigation + crono navigation
    [crono.cpp, e05_ESP8266_SST_webconf.ino]
2016-03-02 Correction Static IP + crono navi
    [crono.cpp, e05_ESP8266_SST_webconf.ino]
2016-03-02 bug correction for commit 362098f74123896f8e630132e0800989ccdb50a1
    [e05_ESP8266_SST_webconf.ino]
2016-03-02 OTA webupdater fix
    It don't work with actual ESP Core
    [e05_ESP8266_SST_webconf.ino]
2016-03-03 displaybright bugfix try to solve setpoint bug on crono
    [crono.cpp, e05_ESP8266_SST_webconf.ino, encoder.cpp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]
2016-03-03 bugfix navigation crono + setpoint :)
    [crono.cpp]
2016-03-03 bypass delay for switch
2016-03-03 bugfix setpoint navigation on crono
    [crono.cpp]
2016-03-06 WORK IN PROGRESS
    MODIFIED SetThermostatON for new T31 bugfix of Souliss Framework
    [e05_ESP8266_SST_webconf.ino]
2016-03-08 heating/cooling bit changed
    New thermostat ON function!!!
2016-03-24 Button click fixed
2016-04-20 Adding 3D front cover prototype
    [Studio.skp, Taglio.dwg]
2016-05-25 Compilazione con IDE 1.6.8 e ESP core 2.2.0
    Non compila la libreria menusystem
2016-06-02 Now ArduinoOta work!!
    Flash Mode DIO
    Flash frequency 40 MHz
    CPU frequency 160 MHz
    Flash size: 1Mb (64K SPIFFS)
    Autoconfiguration Mode don't work
2016-06-09 Issue Menu responsive #20 https://github.com/mcbittech/souliss-smart-thermostat-WiFi/issues/20
    Resa più reattiva la navigazione del menu
    [e05_ESP8266_SST_webconf.ino]
2016-08-13 isNan control for temperature and humidity
2016-08-18 some bugfix for Layout2
    [e05_ESP8266_SST_webconf.ino]
2016-08-23 Buffix on refresh after power off
2016-09-21 added library ArduinoJson
2016-09-27 new_mod_dcdj
    solved issue:
    #30
    #29
    #28
    #17
    #15
    before go to master branch we take some time to test
    [crono.cpp, e05_ESP8266_SST_webconf.ino]
2016-10-02 Publish message HEAT ON or OFF #define SST_HEAT_ONOFF 0xF001,0x0B U8 HEAT_ON = 0X01; U8 HEAT_OFF = 0X00;
2016-10-28 Avanzamento a versione 1.0
    Logica Termostato e T52 inseriti nello stesso ciclo FAST_510ms()
    Prima erano temporizzati diversamente ed a volte sembravano esserci disallineamenti tra i due valori letti da SoulissApp e Openhab
2016-12-03 constant TIMER_DISPLAY_SETPOINT to 4 seconds bugfix getLayout1
    [constants.h, e05_ESP8266_SST_webconf.ino]
2016-12-05 patch with yield() on crono while
    it seems to be an overflow bug on buffer of SDK, on WiFi code
    [e05_ESP8266_SST_webconf.ino]
2016-12-12 e06_ESP_SST_RemoteHeatingRelay example
    example of remote relay node
2017-11-22 working on issue #40
    [SST_Eclipse.ino, encoder.cpp]
2017-12-28 add Fritzing project and some cover photos
    [sst_pcb.fzz]
2017-12-28 industrial board design kicad project files (thanks to Michele[michele@titino.eu])
    [SST_V2_2b.sch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]
